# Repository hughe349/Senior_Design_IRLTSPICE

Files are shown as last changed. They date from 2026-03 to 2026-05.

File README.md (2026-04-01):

# IRLTSPICE - A Senior Design Project
 > *Zach DeNeve, Parker Hitchcock, Clayton Hughes, Micah Samuel*

## Overview

LTspice + irl = IRLTSPICE! IRLTSPICE is a configuratble analog circuit.

## Project Structure
The senior design project uses a monorepo architecture with the following sub-directories:
- `hardware/` Hardware schematics
- `firmware/` Microcontroller firmware
- `software/` On-PC software
- `evilware/` Evil Circuits and Code

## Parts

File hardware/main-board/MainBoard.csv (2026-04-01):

Reference | Qty | Value | DNP | DKPN | Exclude from BOM | Exclude from Board | Footprint | Datasheet
U31 | 1 | XTPS55285VALR |  | XTPS55285VALR |  |  | SeniorDesignFP:TPS55285 | https://www.ti.com/lit/gpn/tps55285
Cout3 | 1 | 33u |  | TPSB336K016R0350 |  |  | Capacitor_Tantalum_SMD:CP_EIA-3528-21_Kemet-B_HandSolder | ~
U32 | 1 | TPS54202DDC |  | TPS54202DDCR |  |  | Package_TO_SOT_SMD:SOT-23-6 | http://www.ti.com/lit/ds/symlink/tps54202.pdf
U28 | 1 | TL071 |  | TL071HIDR |  |  | Package_SO:SOIC-8_3.9x4.9mm_P1.27mm | http://www.ti.com/lit/ds/symlink/tl071.pdf
U25 | 1 | TL071 |  | TL071HIDR |  |  | Package_SO:SOIC-8_3.9x4.9mm_P1.27mm | http://www.ti.com/lit/ds/symlink/tl071.pdf
U22 | 1 | TL071 |  | TL071HIDR |  |  | Package_SO:SOIC-8_3.9x4.9mm_P1.27mm | http://www.ti.com/lit/ds/symlink/tl071.pdf
U19 | 1 | TL071 |  | TL071HIDR |  |  | Package_SO:SOIC-8_3.9x4.9mm_P1.27mm | http://www.ti.com/lit/ds/symlink/tl071.pdf
U16 | 1 | TL071 |  | TL071HIDR |  |  | Package_SO:SOIC-8_3.9x4.9mm_P1.27mm | http://www.ti.com/lit/ds/symlink/tl071.pdf
U13 | 1 | TL071 |  | TL071HIDR |  |  | Package_SO:SOIC-8_3.9x4.9mm_P1.27mm | http://www.ti.com/lit/ds/symlink/tl071.pdf
U10 | 1 | TL071 |  | TL071HIDR |  |  | Package_SO:SOIC-8_3.9x4.9mm_P1.27mm | http://www.ti.com/lit/ds/symlink/tl071.pdf
U7 | 1 | TL071 |  | TL071HIDR |  |  | Package_SO:SOIC-8_3.9x4.9mm_P1.27mm | http://www.ti.com/lit/ds/symlink/tl071.pdf
U6 | 1 | TL071 |  | TL071HIDR |  |  | Package_SO:SOIC-8_3.9x4.9mm_P1.27mm | http://www.ti.com/lit/ds/symlink/tl071.pdf
U5 | 1 | TL071 |  | TL071HIDR |  |  | Package_SO:SOIC-8_3.9x4.9mm_P1.27mm | http://www.ti.com/lit/ds/symlink/tl071.pdf
U4 | 1 | TL071 |  | TL071HIDR |  |  | Package_SO:SOIC-8_3.9x4.9mm_P1.27mm | http://www.ti.com/lit/ds/symlink/tl071.pdf
U3 | 1 | TL071 |  | TL071HIDR |  |  | Package_SO:SOIC-8_3.9x4.9mm_P1.27mm | http://www.ti.com/lit/ds/symlink/tl071.pdf
U37 | 1 | STM32F091RCTx |  | STM32F091RC |  |  | Package_QFP:LQFP-64_10x10mm_P0.5mm | https://www.st.com/resource/en/datasheet/stm32f091rc.pdf
L2 | 1 | 10u |  | SRN6045-100M |  |  | Inductor_SMD:L_Bourns_SRN6045TA | ~
SW4 | 1 | SW_SPST |  | SKQGABE010 |  |  | Button_Switch_SMD:SW_SPST_SKQG_WithoutStem | ~
SW3 | 1 | SW_SPST |  | SKQGABE010 |  |  | Button_Switch_SMD:SW_SPST_SKQG_WithoutStem | ~
D12 | 1 | BLUELED |  | QBLP631-IB5-2897 |  |  | Diode_SMD:D_0805_2012Metric_Pad1.15x1.40mm_HandSolder | ~
J9 | 1 | Barrel_Jack |  | PJ-063AH |  |  | Connector_BarrelJack:BarrelJack_CUI_PJ-063AH_Horizontal | ~
SW2 | 1 | SW_SP3T |  | OS103011MS8QP1 |  |  | Button_Switch_THT:SW_Slide_SP3T_Straight_CK_OS103012MU1QP1 | ~
SW1 | 1 | SW_SP3T |  | OS103011MS8QP1 |  |  | Button_Switch_THT:SW_Slide_SP3T_Straight_CK_OS103012MU1QP1 | ~
L1 | 1 | 12u |  | NPI43C120MTRF |  |  | SeniorDesignFP:IND_4532-WE-PD2_WRE-L | ~
Cinx1 | 1 | 4.7u |  | MSASU32MSB7475MPNA01 |  |  | Capacitor_SMD:C_1210_3225Metric_Pad1.33x2.70mm_HandSolder | ~
D13 | 1 | REDLED |  | LS R976-NR-1-0-20-R18 |  |  | Diode_SMD:D_0805_2012Metric_Pad1.15x1.40mm_HandSolder | ~
D9 | 1 | REDLED |  | LS R976-NR-1-0-20-R18 |  |  | Diode_SMD:D_0805_2012Metric_Pad1.15x1.40mm_HandSolder | ~
C22 | 1 | 10µF |  | LMK107BBJ106MALT |  |  | Capacitor_SMD:C_0603_1608Metric_Pad1.08x0.95mm_HandSolder | ~
C21 | 1 | 10µF |  | LMK107BBJ106MALT |  |  | Capacitor_SMD:C_0603_1608Metric_Pad1.08x0.95mm_HandSolder | ~
U2 | 1 | LM7321MAX/NOPB |  | LM7321MAX/NOPB |  |  | Package_SO:SOIC-8_3.9x4.9mm_P1.27mm | https://www.ti.com/lit/ds/symlink/lm7321.pdf?HQS=dis-dk-null-digikeymode-dsf-pf-null-wwe&ts=1774276721362
U33 | 1 | LM2776 |  | LM2776DBVR |  |  | Package_TO_SOT_SMD:SOT-23-6 | http://www.ti.com/lit/ds/symlink/lm2776.pdf
D14 | 1 | GREENLED |  | LG R971-KN-1-0-20-R18 |  |  | Diode_SMD:D_0805_2012Metric_Pad1.15x1.40mm_HandSolder | ~
D10 | 1 | GREENLED |  | LG R971-KN-1-0-20-R18 |  |  | Diode_SMD:D_0805_2012Metric_Pad1.15x1.40mm_HandSolder | ~
Cout1 | 1 | 47u |  | GRM32ER61C476KE15L |  |  | Capacitor_SMD:C_0805_2012Metric_Pad1.18x1.45mm_HandSolder | ~
Ccomp2 | 1 | 15n |  | GRM155R71C153KA01D |  |  | Capacitor_SMD:C_0402_1005Metric_Pad0.74x0.62mm_HandSolder | ~
Cboot3 | 1 | 100nF |  | GRM155R71C104KA88D |  |  | Capacitor_SMD:C_0402_1005Metric_Pad0.74x0.62mm_HandSolder | ~
Cboot2 | 1 | 100nF |  | GRM155R71C104KA88D |  |  | Capacitor_SMD:C_0402_1005Metric_Pad0.74x0.62mm_HandSolder | ~
Ccomp1 | 1 | 240p |  | GRM1555C1H241JA01D |  |  | Capacitor_SMD:C_0402_1005Metric_Pad0.74x0.62mm_HandSolder | ~
Cff1 | 1 | 56p |  | GRM0335C1E560JA01D |  |  | Capacitor_SMD:C_0201_0603Metric_Pad0.64x0.40mm_HandSolder | ~
U35 | 1 | FT232RL |  | FT232RNL-TUBE |  |  | Package_SO:SSOP-28_5.3x10.2mm_P0.65mm | https://www.ftdichip.com/Support/Documents/DataSheets/ICs/DS_FT232R.pdf
R8 | 1 | 10kΩ |  | ESR03EZPF1002 |  |  | Resistor_SMD:R_0603_1608Metric_Pad0.98x0.95mm_HandSolder | ~
R7 | 1 | 10kΩ |  | ESR03EZPF1002 |  |  | Resistor_SMD:R_0603_1608Metric_Pad0.98x0.95mm_HandSolder | ~
R5 | 1 | 10kΩ |  | ESR03EZPF1002 |  |  | Resistor_SMD:R_0603_1608Metric_Pad0.98x0.95mm_HandSolder | ~
R3 | 1 | 10k |  | ESR03EZPF1002 |  |  | Resistor_SMD:R_0603_1608Metric_Pad0.98x0.95mm_HandSolder | ~
R2 | 1 | 10k |  | ESR03EZPF1002 |  |  | Resistor_SMD:R_0603_1608Metric_Pad0.98x0.95mm_HandSolder | ~
R10 | 1 | 150Ω |  | ERA-3AEB151V |  |  | Resistor_SMD:R_0603_1608Metric_Pad0.98x0.95mm_HandSolder | ~
R9 | 1 | 150Ω |  | ERA-3AEB151V |  |  | Resistor_SMD:R_0603_1608Metric_Pad0.98x0.95mm_HandSolder | ~
R6 | 1 | 150Ω |  | ERA-3AEB151V |  |  | Resistor_SMD:R_0603_1608Metric_Pad0.98x0.95mm_HandSolder | ~
R4 | 1 | 150Ω |  | ERA-3AEB151V |  |  | Resistor_SMD:R_0603_1608Metric_Pad0.98x0.95mm_HandSolder | ~
R1 | 1 | 150Ω |  | ERA-3AEB151V |  |  | Resistor_SMD:R_0603_1608Metric_Pad0.98x0.95mm_HandSolder | ~
Rcomp1 | 1 | 8.87k |  | CRCW04028K87FKED |  |  | Resistor_SMD:R_0402_1005Metric_Pad0.72x0.64mm_HandSolder | ~
Rfbb2 | 1 | 6.04k |  | CRCW04026K04FKED |  |  | Resistor_SMD:R_0402_1005Metric_Pad0.72x0.64mm_HandSolder | ~
Rmode1 | 1 | 24.9k |  | CRCW040224K9FKED |  |  | Resistor_SMD:R_0402_1005Metric_Pad0.72x0.64mm_HandSolder | ~
Rfbb1 | 1 | 22.1k |  | CRCW040222K1FKED |  |  | Resistor_SMD:R_0402_1005Metric_Pad0.72x0.64mm_HandSolder | ~
Rent1 | 1 | 261k |  | CRCW0402261KFKED |  |  | Resistor_SMD:R_0402_1005Metric_Pad0.72x0.64mm_HandSolder | ~
Rfbt2 | 1 | 102k |  | CRCW0402102KFKED |  |  | Resistor_SMD:R_0402_1005Metric_Pad0.72x0.64mm_HandSolder | ~
Rfbt1 | 1 | 100k |  | CRCW0402100KFKED |  |  | Resistor_SMD:R_0402_1005Metric_Pad0.72x0.64mm_HandSolder | ~
Renb1 | 1 | 100k |  | CRCW0402100KFKED |  |  | Resistor_SMD:R_0402_1005Metric_Pad0.72x0.64mm_HandSolder | ~
C19 | 1 | 2.2u |  | CL10B225KP8NNNC |  |  | Capacitor_SMD:C_0603_1608Metric_Pad1.08x0.95mm_HandSolder | ~
C18 | 1 | 2.2u |  | CL10B225KP8NNNC |  |  | Capacitor_SMD:C_0603_1608Metric_Pad1.08x0.95mm_HandSolder | ~
U30 | 1 | CD22M3494MQZ |  | CD22M3494MQZ |  |  | SeniorDesignFP:PLCC44_16P66X16P66_INR-M
U29 | 1 | CD22M3494MQZ |  | CD22M3494MQZ |  |  | SeniorDesignFP:PLCC44_16P66X16P66_INR-M
U24 | 1 | CD22M3494MQZ |  | CD22M3494MQZ |  |  | SeniorDesignFP:PLCC44_16P66X16P66_INR-M
U23 | 1 | CD22M3494MQZ |  | CD22M3494MQZ |  |  | SeniorDesignFP:PLCC44_16P66X16P66_INR-M
U18 | 1 | CD22M3494MQZ |  | CD22M3494MQZ |  |  | SeniorDesignFP:PLCC44_16P66X16P66_INR-M
U17 | 1 | CD22M3494MQZ |  | CD22M3494MQZ |  |  | SeniorDesignFP:PLCC44_16P66X16P66_INR-M
U12 | 1 | CD22M3494MQZ |  | CD22M3494MQZ |  |  | SeniorDesignFP:PLCC44_16P66X16P66_INR-M
U11 | 1 | CD22M3494MQZ |  | CD22M3494MQZ |  |  | SeniorDesignFP:PLCC44_16P66X16P66_INR-M
U1 | 1 | CD22M3494MQZ |  | CD22M3494MQZ |  |  | SeniorDesignFP:PLCC44_16P66X16P66_INR-M
Coutx3 | 1 | 10µF |  | C3225X7R1H106M250AC |  |  | Capacitor_SMD:C_1210_3225Metric_Pad1.33x2.70mm_HandSolder | ~
F4 | 1 | 500mA |  | C2Q500 |  |  | Fuse:Fuse_0603_1608Metric_Pad1.05x0.95mm_HandSolder | ~
F3 | 1 | 500mA |  | C2Q500 |  |  | Fuse:Fuse_0603_1608Metric_Pad1.05x0.95mm_HandSolder | ~
F2 | 1 | 500mA |  | C2Q500 |  |  | Fuse:Fuse_0603_1608Metric_Pad1.05x0.95mm_HandSolder | ~
F1 | 1 | 500mA |  | C2Q500 |  |  | Fuse:Fuse_0603_1608Metric_Pad1.05x0.95mm_HandSolder | ~
Cin3 | 1 | 3.3µF |  | C1608X5R1V335K080AC |  |  | Capacitor_SMD:C_1210_3225Metric_Pad1.33x2.70mm_HandSolder | ~
Cvcc1 | 1 | 4.7u |  | C1608X5R1C475K080AC |  |  | Capacitor_SMD:C_0201_0603Metric_Pad0.64x0.40mm_HandSolder | ~
Cinx2 | 1 | 1µF |  | C1005X5R1V105K050BC |  |  | Capacitor_SMD:C_0402_1005Metric_Pad0.74x0.62mm_HandSolder | ~
Cboot1 | 1 | 100nF |  | C0805C104M5RACTU |  |  | Capacitor_SMD:C_0805_2012Metric_Pad1.18x1.45mm_HandSolder | ~
Coutx1 | 1 | 1µF |  | C0603C105Z8VACTU |  |  | Capacitor_SMD:C_0201_0603Metric_Pad0.64x0.40mm_HandSolder | ~
C30 | 1 | 1µF |  | C0603C105K4RACTU |  |  | Capacitor_SMD:C_0603_1608Metric_Pad1.08x0.95mm_HandSolder | ~
C29 | 1 | 1µF |  | C0603C105K4RACTU |  |  | Capacitor_SMD:C_0603_1608Metric_Pad1.08x0.95mm_HandSolder | ~
C17 | 1 | 1µF |  | C0603C105K4RACTU |  |  | Capacitor_SMD:C_0603_1608Metric_Pad1.08x0.95mm_HandSolder | ~
C13 | 1 | 1µF |  | C0603C105K4RACTU |  |  | Capacitor_SMD:C_0603_1608Metric_Pad1.08x0.95mm_HandSolder | ~
C9 | 1 | 1µF |  | C0603C105K4RACTU |  |  | Capacitor_SMD:C_0603_1608Metric_Pad1.08x0.95mm_HandSolder | ~
C5 | 1 | 1µF |  | C0603C105K4RACTU |  |  | Capacitor_SMD:C_0603_1608Metric_Pad1.08x0.95mm_HandSolder | ~
C1 | 1 | 1µF |  | C0603C105K4RACTU |  |  | Capacitor_SMD:C_0603_1608Metric_Pad1.08x0.95mm_HandSolder | ~
C27 | 1 | 100nF |  | C0603C104K5RACTU |  |  | Capacitor_SMD:C_0603_1608Metric_Pad1.08x0.95mm_HandSolder | ~
C26 | 1 | 100nF |  | C0603C104K5RACTU |  |  | Capacitor_SMD:C_0603_1608Metric_Pad1.08x0.95mm_HandSolder | ~
C25 | 1 | 100nF |  | C0603C104K5RACTU |  |  | Capacitor_SMD:C_0603_1608Metric_Pad1.08x0.95mm_HandSolder | ~
C24 | 1 | 100nF |  | C0603C104K5RACTU |  |  | Capacitor_SMD:C_0603_1608Metric_Pad1.08x0.95mm_HandSolder | ~
C23 | 1 | 100nF |  | C0603C104K5RACTU |  |  | Capacitor_SMD:C_0603_1608Metric_Pad1.08x0.95mm_HandSolder | ~
C20 | 1 | 100nF |  | C0603C104K5RACTU |  |  | Capacitor_SMD:C_0603_1608Metric_Pad1.08x0.95mm_HandSolder | ~
C14 | 1 | 100nF |  | C0603C104K5RACTU |  |  | Capacitor_SMD:C_0603_1608Metric_Pad1.08x0.95mm_HandSolder | ~
C10 | 1 | 100nF |  | C0603C104K5RACTU |  |  | Capacitor_SMD:C_0603_1608Metric_Pad1.08x0.95mm_HandSolder | ~
C6 | 1 | 100nF |  | C0603C104K5RACTU |  |  | Capacitor_SMD:C_0603_1608Metric_Pad1.08x0.95mm_HandSolder | ~
C2 | 1 | 100nF |  | C0603C104K5RACTU |  |  | Capacitor_SMD:C_0603_1608Metric_Pad1.08x0.95mm_HandSolder | ~
C28 | 1 | 10nF |  | C0603C103K5RACTU |  |  | Capacitor_SMD:C_0603_1608Metric_Pad1.08x0.95mm_HandSolder | ~
C15 | 1 | 10nF |  | C0603C103K5RACTU |  |  | Capacitor_SMD:C_0603_1608Metric_Pad1.08x0.95mm_HandSolder | ~
C11 | 1 | 10nF |  | C0603C103K5RACTU |  |  | Capacitor_SMD:C_0603_1608Metric_Pad1.08x0.95mm_HandSolder | ~
C7 | 1 | 10nF |  | C0603C103K5RACTU |  |  | Capacitor_SMD:C_0603_1608Metric_Pad1.08x0.95mm_HandSolder | ~
C3 | 1 | 10nF |  | C0603C103K5RACTU |  |  | Capacitor_SMD:C_0603_1608Metric_Pad1.08x0.95mm_HandSolder | ~
C16 | 1 | 1nF |  | C0603C102K5RACTU |  |  | Capacitor_SMD:C_0603_1608Metric_Pad1.08x0.95mm_HandSolder | ~
C12 | 1 | 1nF |  | C0603C102K5RACTU |  |  | Capacitor_SMD:C_0603_1608Metric_Pad1.08x0.95mm_HandSolder | ~
C8 | 1 | 1nF |  | C0603C102K5RACTU |  |  | Capacitor_SMD:C_0603_1608Metric_Pad1.08x0.95mm_HandSolder | ~
C4 | 1 | 1nF |  | C0603C102K5RACTU |  |  | Capacitor_SMD:C_0603_1608Metric_Pad1.08x0.95mm_HandSolder | ~
FB1 | 1 | 120R |  | BLM18PG121SN1D |  |  | Inductor_SMD:L_0603_1608Metric_Pad1.05x0.95mm_HandSolder | ~
D11 | 1 | BAT60JFILM |  | BAT60JFILM |  |  | Diode_SMD:D_SOD-323_HandSoldering | ~
U27 | 1 | AD5263BRUZ200 |  | AD5263BRUZ200-R7 |  |  | SeniorDesignFP:SOP65P640X120-24N
U26 | 1 | AD5263BRUZ200 |  | AD5263BRUZ200-R7 |  |  | SeniorDesignFP:SOP65P640X120-24N
U21 | 1 | AD5263BRUZ200 |  | AD5263BRUZ200-R7 |  |  | SeniorDesignFP:SOP65P640X120-24N
U20 | 1 | AD5263BRUZ200 |  | AD5263BRUZ200-R7 |  |  | SeniorDesignFP:SOP65P640X120-24N
U15 | 1 | AD5263BRUZ200 |  | AD5263BRUZ200-R7 |  |  | SeniorDesignFP:SOP65P640X120-24N
U14 | 1 | AD5263BRUZ200 |  | AD5263BRUZ200-R7 |  |  | SeniorDesignFP:SOP65P640X120-24N
U9 | 1 | AD5263BRUZ200 |  | AD5263BRUZ200-R7 |  |  | SeniorDesignFP:SOP65P640X120-24N
U8 | 1 | AD5263BRUZ200 |  | AD5263BRUZ200-R7 |  |  | SeniorDesignFP:SOP65P640X120-24N
U38 | 1 | 74HC164 |  | 74HC164D |  |  | Package_SO:SOIC-14_3.9x8.7mm_P1.27mm | https://assets.nexperia.com/documents/data-sheet/74HC_HCT164.pdf
U36 | 1 | 74HC164 |  | 74HC164D |  |  | Package_SO:SOIC-14_3.9x8.7mm_P1.27mm | https://assets.nexperia.com/documents/data-sheet/74HC_HCT164.pdf
U34 | 1 | 74HC164 |  | 74HC164D |  |  | Package_SO:SOIC-14_3.9x8.7mm_P1.27mm | https://assets.nexperia.com/documents/data-sheet/74HC_HCT164.pdf
Cin1 | 1 | 22u |  | 35SVPF22M |  |  | SeniorDesignFP:CAP_EEFK_C_PAN | ~
D8 | 1 | 1N4148WT |  | 1N4148W |  |  | Diode_SMD:D_SOD-123 | https://www.diodes.com/assets/Datasheets/ds30396.pdf
D7 | 1 | 1N4148WT |  | 1N4148W |  |  | Diode_SMD:D_SOD-123 | https://www.diodes.com/assets/Datasheets/ds30396.pdf
D6 | 1 | 1N4148WT |  | 1N4148W |  |  | Diode_SMD:D_SOD-123 | https://www.diodes.com/assets/Datasheets/ds30396.pdf
D5 | 1 | 1N4148WT |  | 1N4148W |  |  | Diode_SMD:D_SOD-123 | https://www.diodes.com/assets/Datasheets/ds30396.pdf
D4 | 1 | 1N4148WT |  | 1N4148W |  |  | Diode_SMD:D_SOD-123 | https://www.diodes.com/assets/Datasheets/ds30396.pdf
D3 | 1 | 1N4148WT |  | 1N4148W |  |  | Diode_SMD:D_SOD-123 | https://www.diodes.com/assets/Datasheets/ds30396.pdf
D2 | 1 | 1N4148WT |  | 1N4148W |  |  | Diode_SMD:D_SOD-123 | https://www.diodes.com/assets/Datasheets/ds30396.pdf
D1 | 1 | 1N4148WT |  | 1N4148W |  |  | Diode_SMD:D_SOD-123 | https://www.diodes.com/assets/Datasheets/ds30396.pdf
J10 | 1 | USB_C_Receptacle_USB2.0_14P |  | 1003-030-01210-TR |  |  | Connector_USB:USB_C_Receptacle_G-Switch_GT-USB-7010ASV | https://www.usb.org/sites/default/files/documents/usb_type-c.zip
J13 | 1 | Conn_01x02_Pin |  |  |  |  | Connector_PinSocket_2.54mm:PinSocket_1x02_P2.54mm_Vertical | ~
J12 | 1 | Conn_01x02_Pin |  |  |  |  | Connector_PinSocket_2.54mm:PinSocket_1x02_P2.54mm_Vertical | ~
J11 | 1 | Conn_02x05_Odd_Even |  |  |  |  | Connector_PinHeader_2.54mm:PinHeader_2x05_P2.54mm_Vertical | ~
J8 | 1 | Conn_01x02_Pin |  |  |  |  | Connector_PinSocket_2.54mm:PinSocket_1x02_P2.54mm_Vertical | ~
J7 | 1 | Conn_01x02_Pin |  |  |  |  | Connector_PinSocket_2.54mm:PinSocket_1x02_P2.54mm_Vertical | ~
J6 | 1 | Conn_01x02_Pin |  |  |  |  | Connector_PinSocket_2.54mm:PinSocket_1x02_P2.54mm_Vertical | ~
J5 | 1 | Conn_01x02_Pin |  |  |  |  | Connector_PinSocket_2.54mm:PinSocket_1x02_P2.54mm_Vertical | ~
J4 | 1 | Conn_01x03_Pin |  |  |  |  | Connector_PinHeader_2.54mm:PinHeader_1x03_P2.54mm_Vertical | ~
J3 | 1 | Conn_01x03_Pin |  |  |  |  | Connector_PinHeader_2.54mm:PinHeader_1x03_P2.54mm_Vertical | ~
J2 | 1 | Conn_01x03_Pin |  |  |  |  | Connector_PinHeader_2.54mm:PinHeader_1x03_P2.54mm_Vertical | ~
J1 | 1 | Conn_01x03_Pin |  |  |  |  | Connector_PinHeader_2.54mm:PinHeader_1x03_P2.54mm_Vertical | ~

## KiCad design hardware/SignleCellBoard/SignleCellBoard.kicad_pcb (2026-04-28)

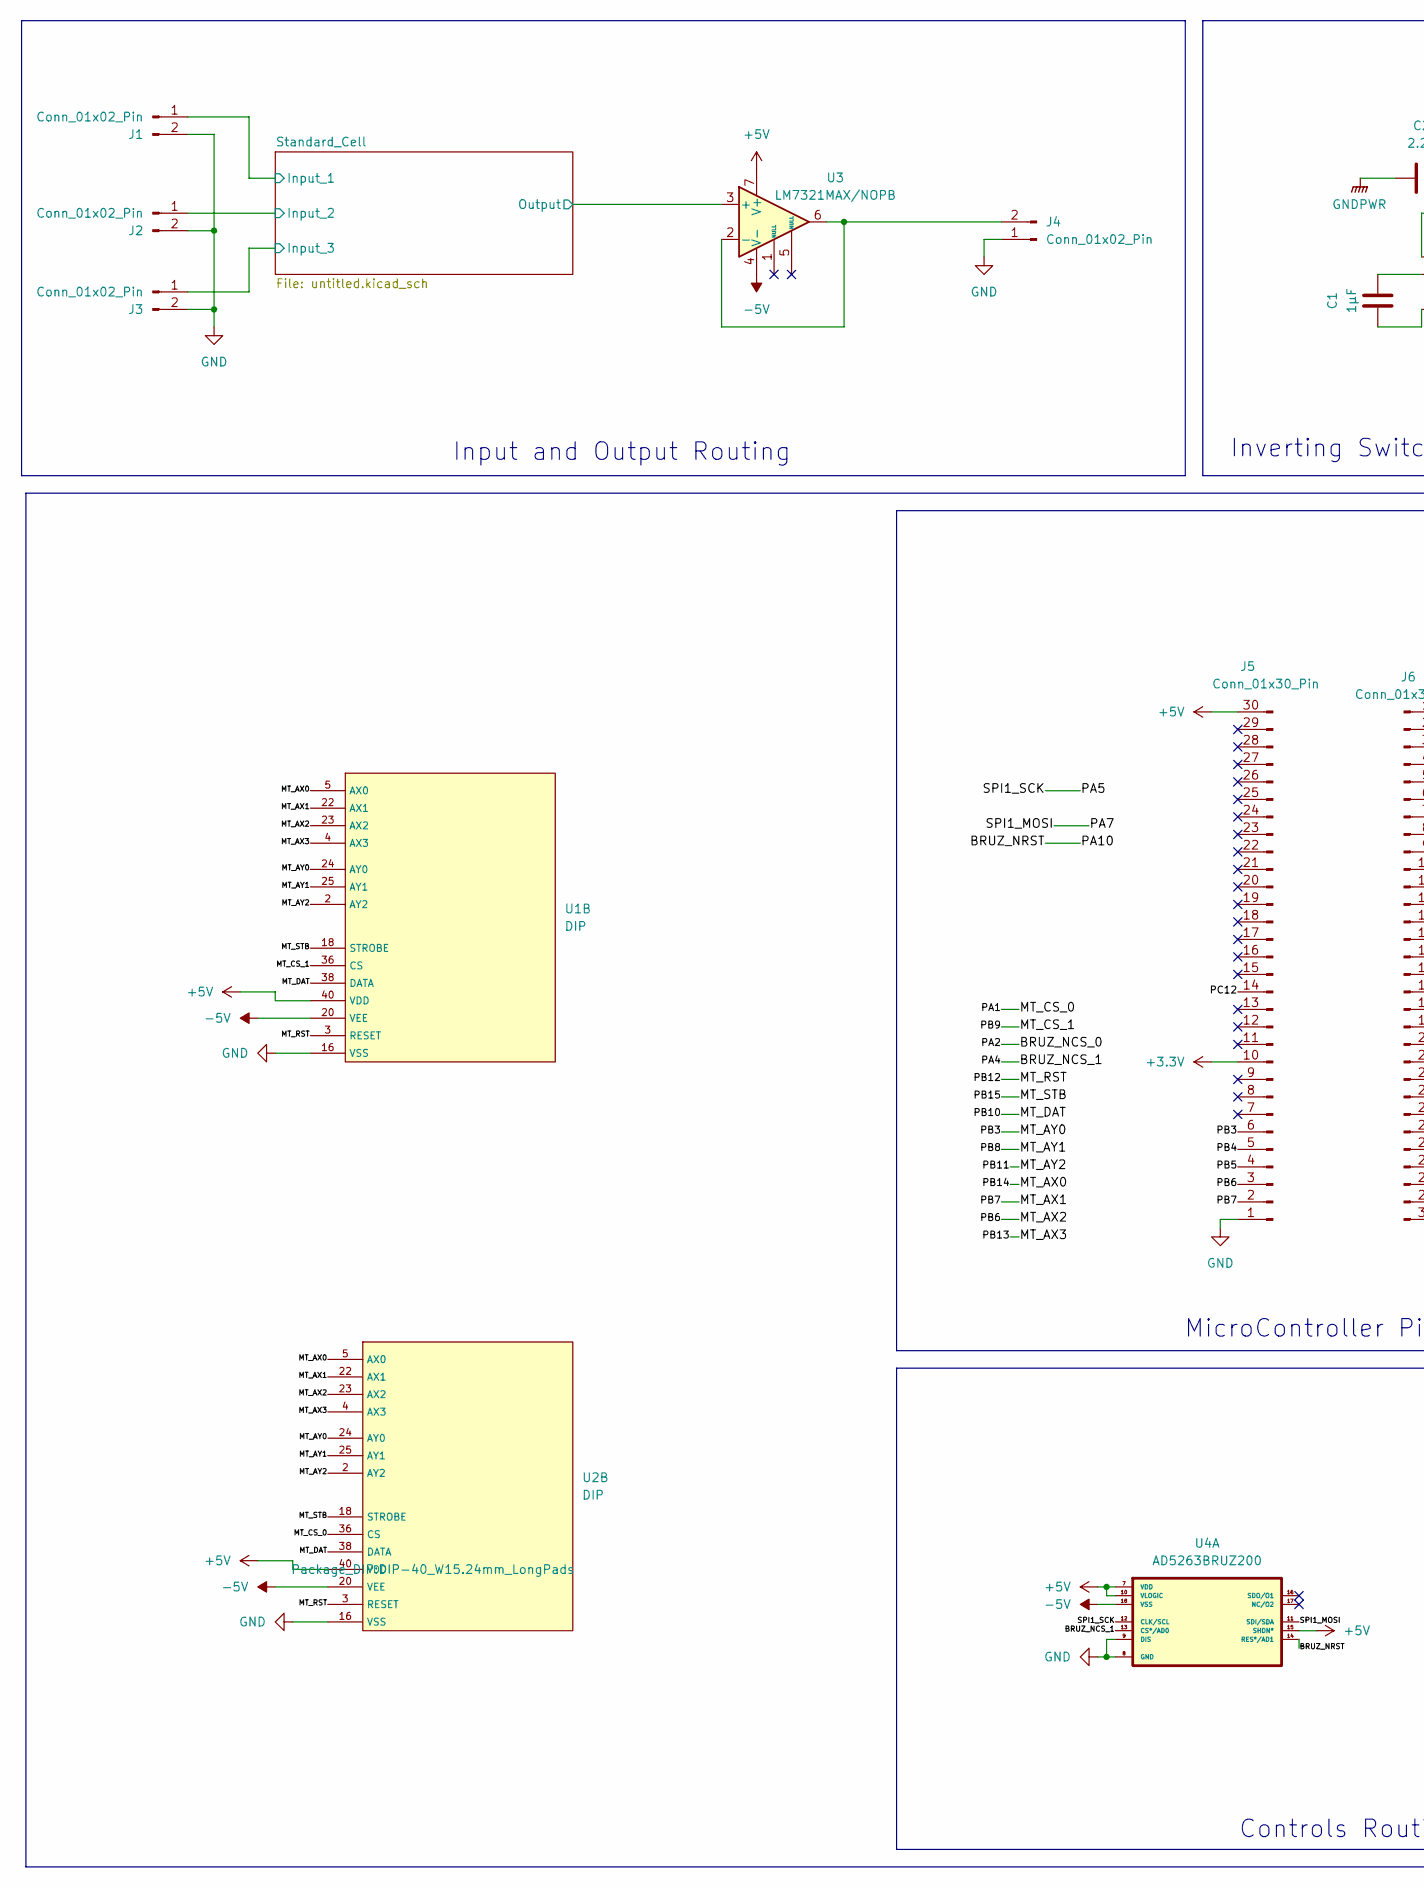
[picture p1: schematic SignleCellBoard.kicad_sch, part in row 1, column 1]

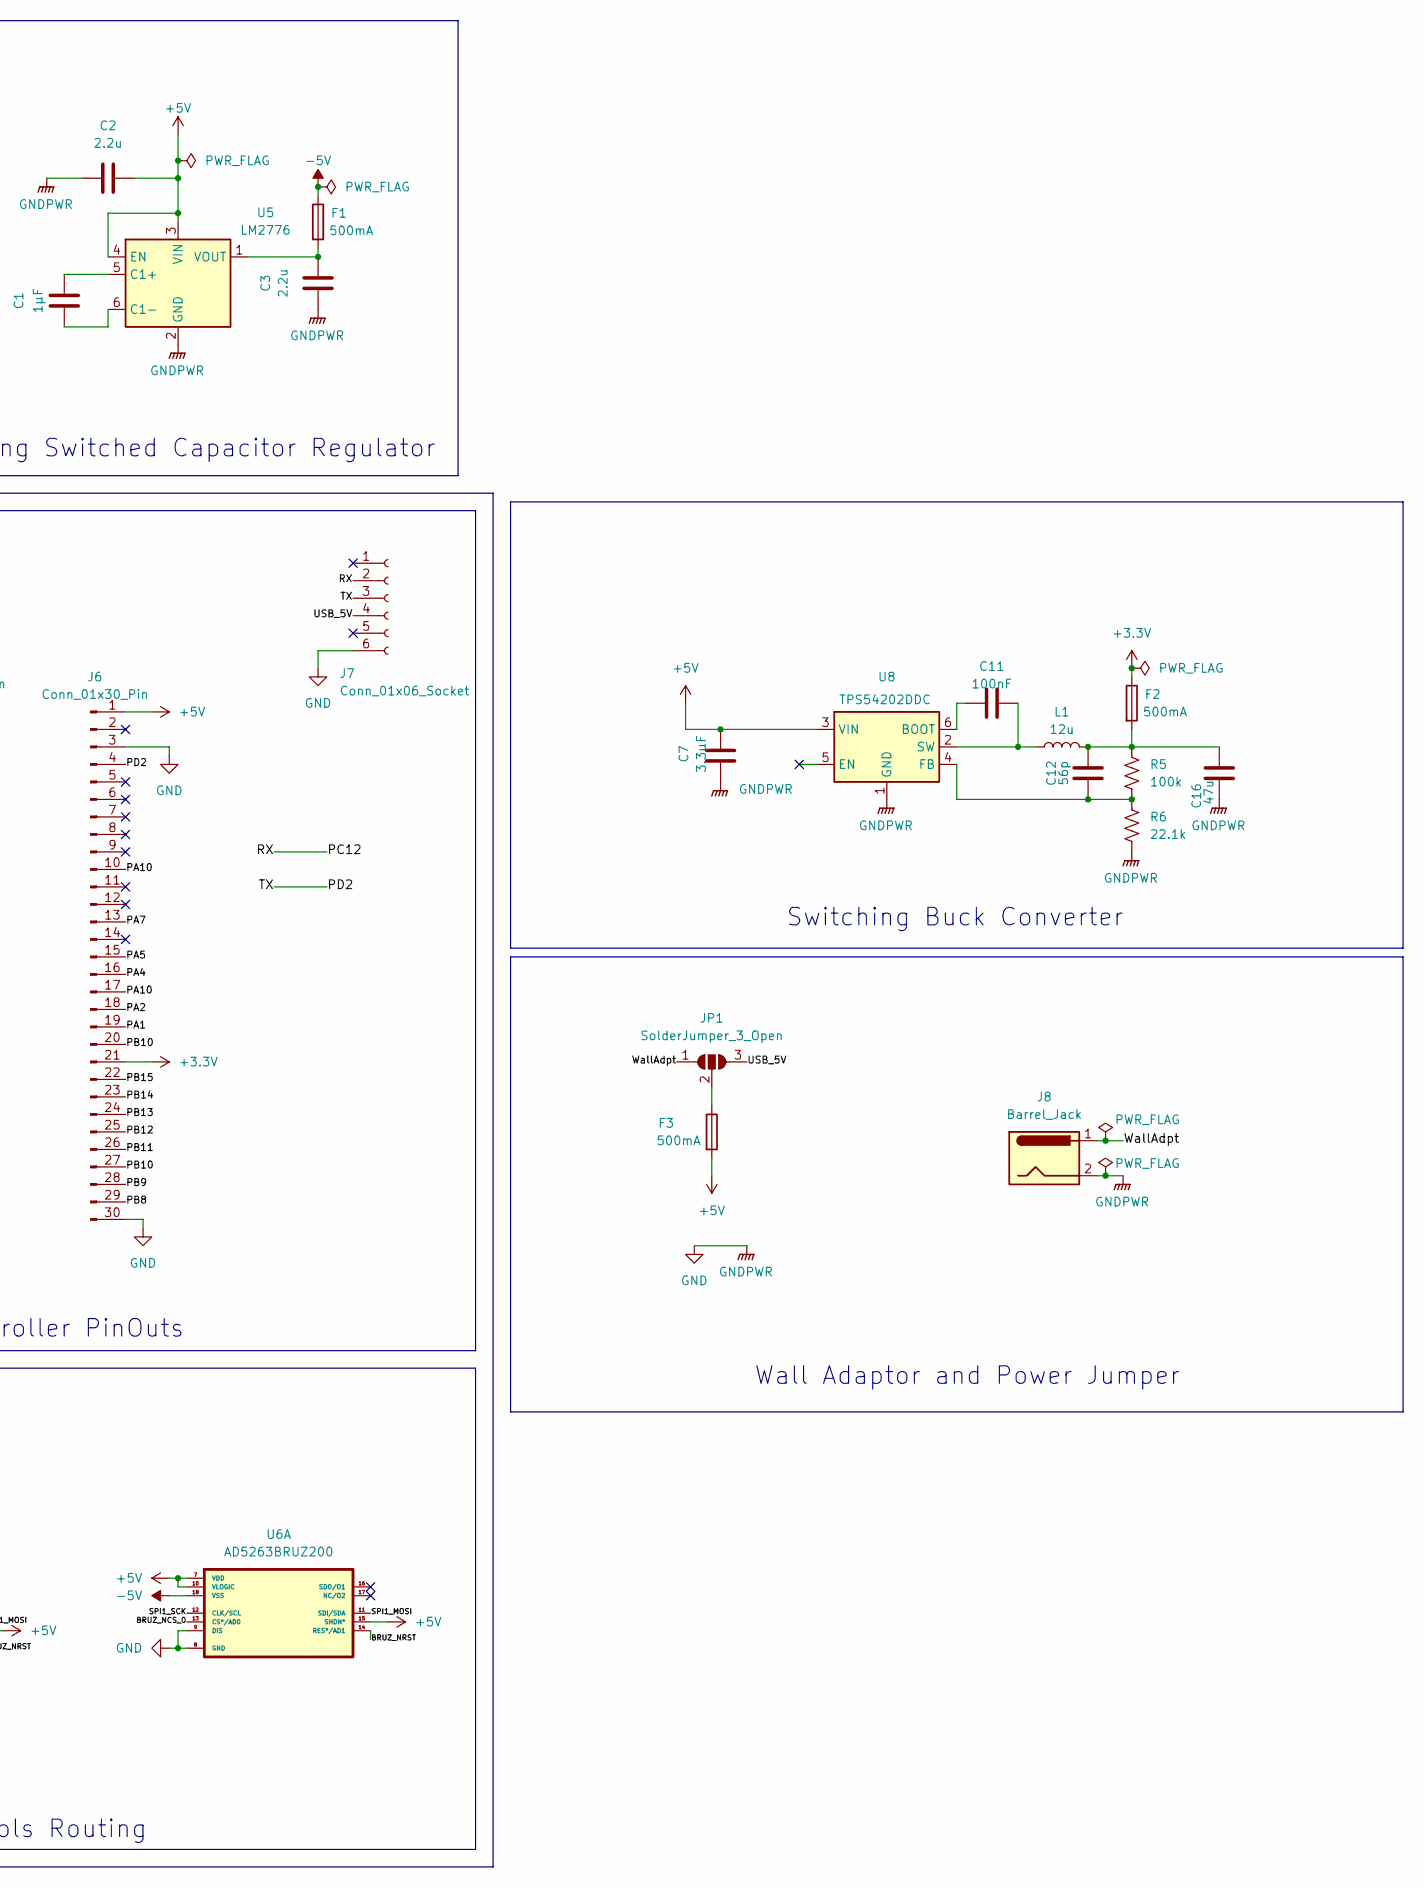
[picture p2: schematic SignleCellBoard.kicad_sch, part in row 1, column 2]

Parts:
C1: 1µF; C_0603_1608Metric_Pad1.08x0.95mm_HandSolder
C2, C3: 2.2u; C_0603_1608Metric_Pad1.08x0.95mm_HandSolder
C7: 3.3µF; C_0805_2012Metric_Pad1.18x1.45mm_HandSolder
C11: 100nF; C_0805_2012Metric_Pad1.18x1.45mm_HandSolder
C12: 56p; C_0603_1608Metric
C16: 47u; C_0805_2012Metric_Pad1.18x1.45mm_HandSolder
F1, F2, F3: 500mA; Fuse_0603_1608Metric_Pad1.05x0.95mm_HandSolder
J1, J2, J3, J4: Conn_01x02_Pin; PinSocket_1x02_P2.54mm_Vertical
J5, J6: Conn_01x30_Pin; PinSocket_1x30_P2.54mm_Vertical
J7: Conn_01x06_Socket; PinSocket_1x06_P2.54mm_Vertical
J8: Barrel_Jack; BarrelJack_CUI_PJ-063AH_Horizontal
JP1: SolderJumper_3_Open; SolderJumper-3_P1.3mm_Open_Pad1.0x1.5mm_NumberLabels
L1: 12u; IND_4532-WE-PD2_WRE-L
R5: 100k; R_0402_1005Metric_Pad0.72x0.64mm_HandSolder
R6: 22.1k; R_0402_1005Metric_Pad0.72x0.64mm_HandSolder
U1, U2: DIP; DIP-40_W15.24mm_LongPads
U3: LM7321MAX/NOPB; SOIC-8_3.9x4.9mm_P1.27mm
U4, U6: AD5263BRUZ200; DIP-24_W15.24mm; MPN AD5263BRUZ200
U5: LM2776; PinHeader_1x06_P2.54mm_Vertical
U8: TPS54202DDC; PinHeader_1x06_P2.54mm_Vertical

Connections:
+3.3V: F2.1, J5.10, J6.21
+5V: C2.2, C7.2, F3.2, J5.30, J6.1, U1.40 (VDD), U2.40 (VDD), U3.7 (V+), U4.7 (VDD), U4.10 (VLOGIC), U4.15 (SHDN*), U5.3 (VIN), U5.4 (EN), U6.7 (VDD), U6.10 (VLOGIC), U6.15 (SHDN*), U8.3 (VIN); also elsewhere on the board
-5V: F1.1, U1.20 (VEE), U2.20 (VEE), U3.4 (V-), U4.18 (VSS), U6.18 (VSS); also elsewhere on the board
/BRUZ_NCS_0: J6.18, U6.13 (CS*/AD0)
/BRUZ_NCS_1: J6.16, U4.13 (CS*/AD0)
/BRUZ_NRST: J6.10, J6.17, U4.14 (RES*/AD1), U6.14 (RES*/AD1)
/MT_AX0: J6.23, U1.5 (AX0), U2.5 (AX0)
/MT_AX1: J5.2, U1.22 (AX1), U2.22 (AX1)
/MT_AX2: J5.3, U1.23 (AX2), U2.23 (AX2)
/MT_AX3: J6.24, U1.4 (AX3), U2.4 (AX3)
/MT_AY0: J5.6, U1.24 (AY0), U2.24 (AY0)
/MT_AY1: J6.29, U1.25 (AY1), U2.25 (AY1)
/MT_AY2: J6.26, U1.2 (AY2), U2.2 (AY2)
/MT_CS_0: J6.19, U2.36 (CS)
/MT_CS_1: J6.28, U1.36 (CS)
/MT_DAT: J6.20, J6.27, U1.38 (DATA), U2.38 (DATA)
/MT_RST: J6.25, U1.3 (RESET), U2.3 (RESET)
/MT_STB: J6.22, U1.18 (STROBE), U2.18 (STROBE)
/PA5: J6.15, U4.12 (CLK/SCL), U6.12 (CLK/SCL)
/PA7: J6.13, U4.11 (SDI/SDA), U6.11 (SDI/SDA)
/PB4: J5.5
/PB5: J5.4
/PC12: J5.14, J7.2
/PD2: J6.4, J7.3
/Standard_Cell/Y0: J1.1; also elsewhere on the board
/Standard_Cell/Y1: J2.1; also elsewhere on the board
/Standard_Cell/Y2: J3.1; also elsewhere on the board
/Standard_Cell/Y3: U3.3 (+); also elsewhere on the board
/USB_5V: J7.4, JP1.3 (B)
/WallAdpt: J8.1, JP1.1 (A)
GND: C2.1, C3.1, C7.1, C16.1, J1.2, J2.2, J3.2, J4.1, J5.1, J6.3, J6.30, J7.6, J8.2, R6.2, U1.16 (VSS), U2.16 (VSS), U4.8 (GND), U4.9 (DIS), U5.2 (GND), U6.8 (GND), U6.9 (DIS), U8.1 (GND); also elsewhere on the board
unnamed: C12.2, C16.2, F2.2, L1.2, R5.1
unnamed: J4.2, U3.2 (-), U3.6
unnamed: F3.1, JP1.2 (C)
unnamed: C1.2, U5.5 (C1+)
unnamed: C1.1, U5.6 (C1-)
unnamed: C3.2, F1.2, U5.1 (VOUT)
unnamed: C11.1, U8.6 (BOOT)
unnamed: C12.1, R5.2, R6.1, U8.4 (FB)
unnamed: C11.2, L1.1, U8.2 (SW)

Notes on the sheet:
MicroController PinOuts
Input and Output Routing
Wall Adaptor and Power Jumper
Inverting Switched Capacitor Regulator
Switching Buck Converter
Controls Routing

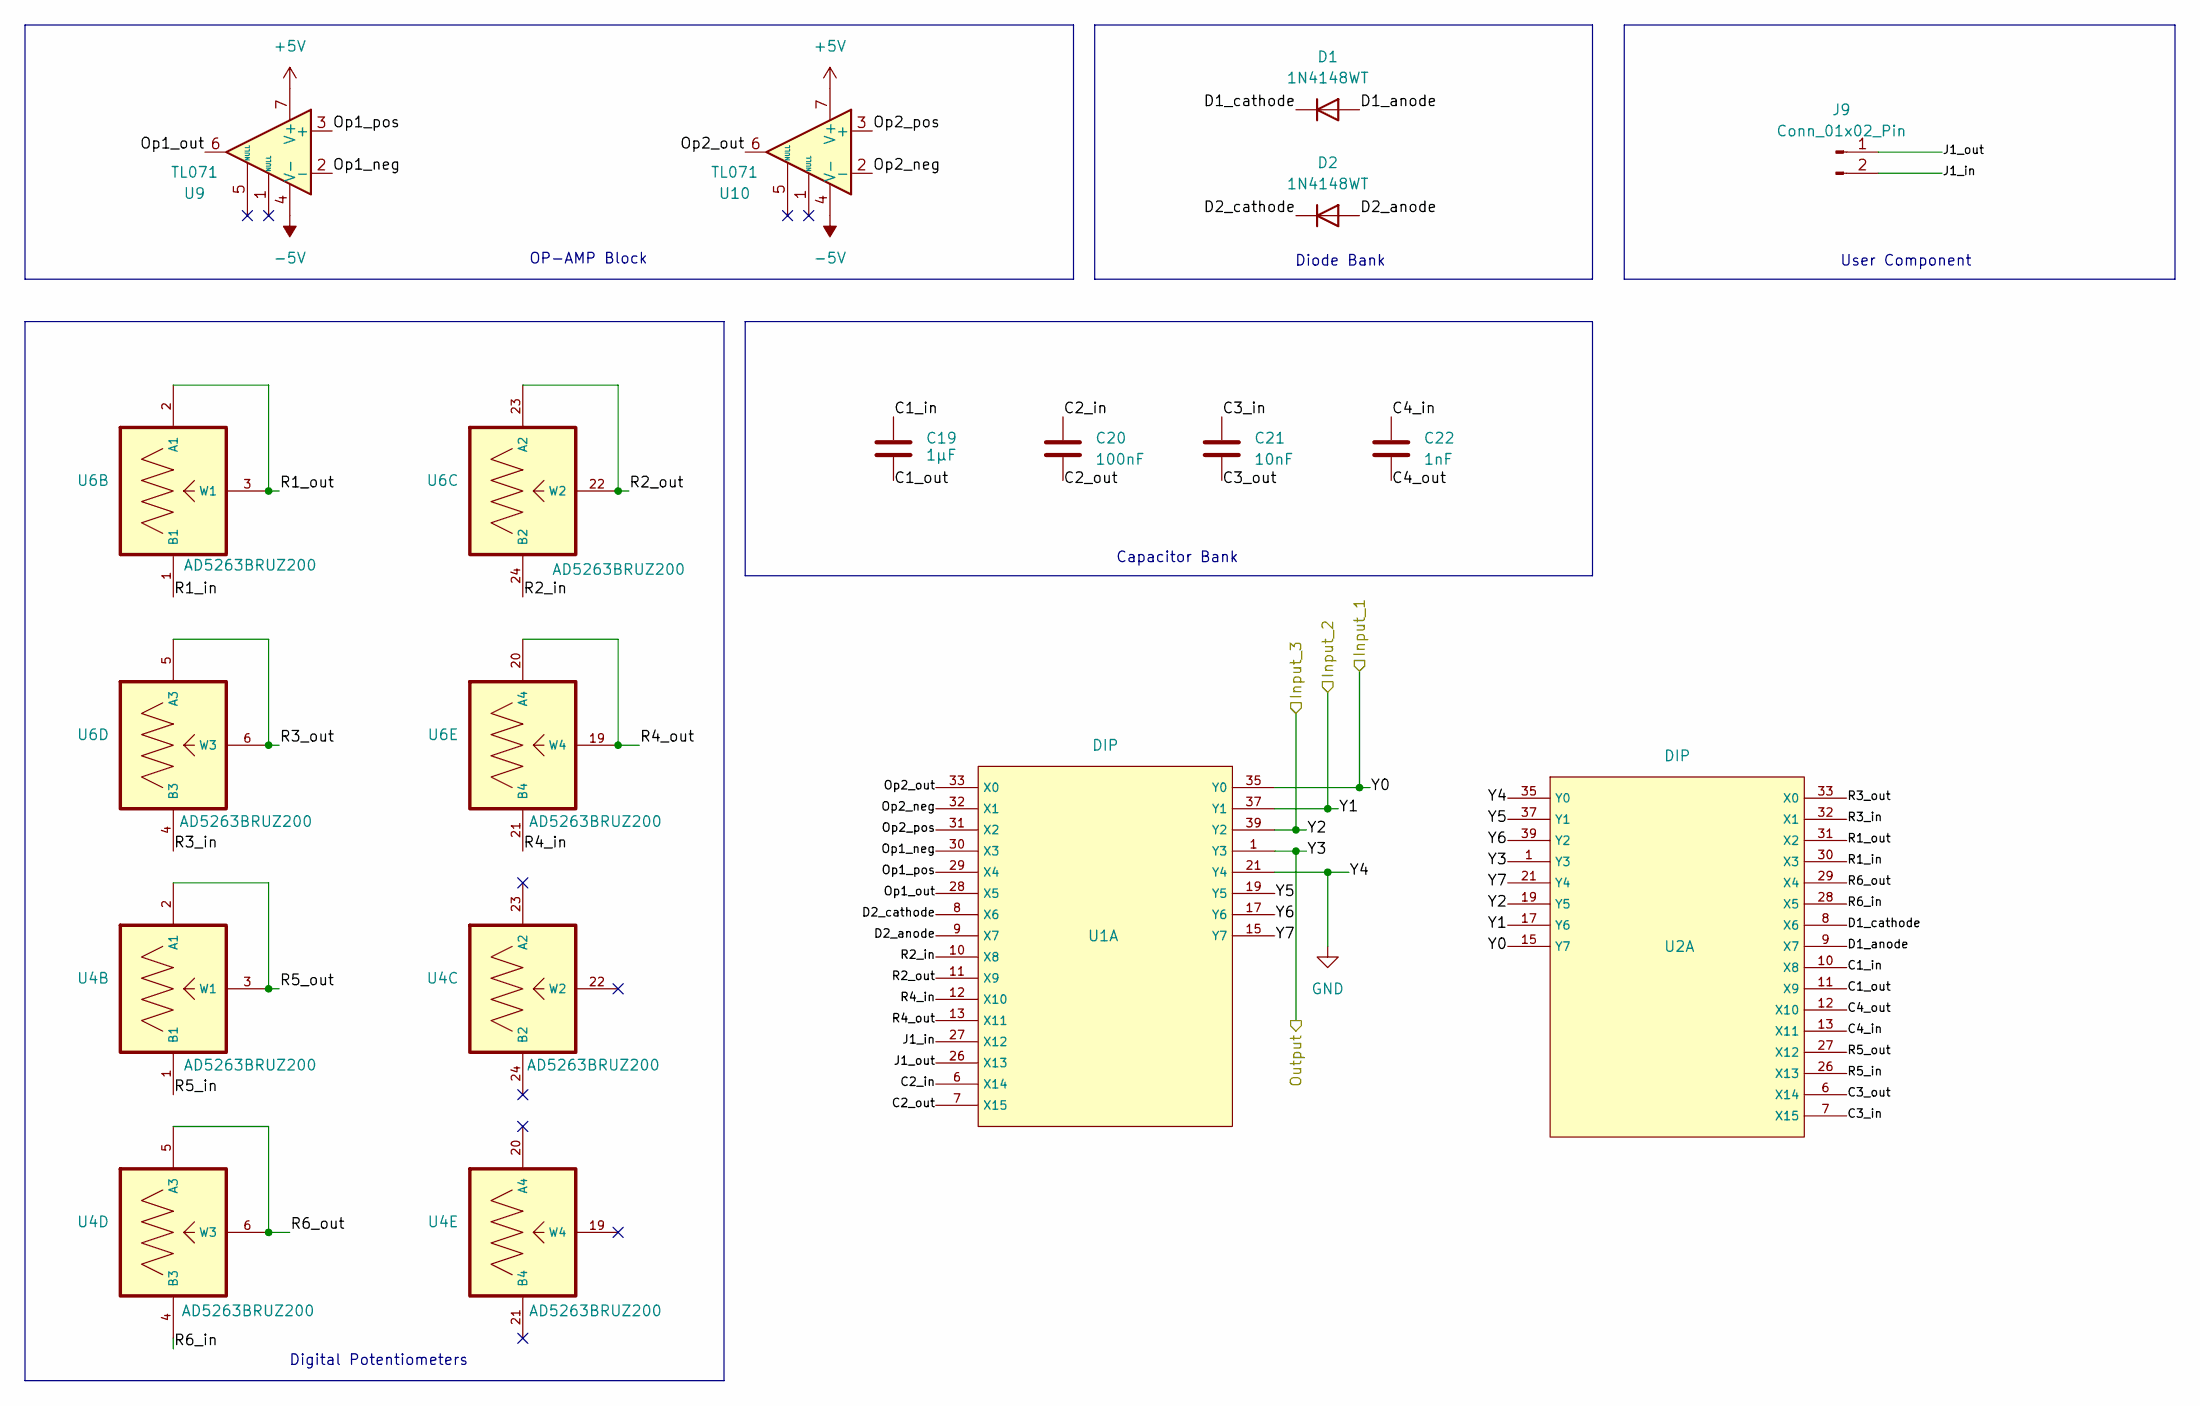
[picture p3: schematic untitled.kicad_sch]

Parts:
C19: 1µF; C_0603_1608Metric_Pad1.08x0.95mm_HandSolder
C20: 100nF; C_0603_1608Metric_Pad1.08x0.95mm_HandSolder
C21: 10nF; C_0603_1608Metric_Pad1.08x0.95mm_HandSolder
C22: 1nF; C_0603_1608Metric_Pad1.08x0.95mm_HandSolder
D1, D2: 1N4148WT; D_SOD-123
J9: Conn_01x02_Pin; PinSocket_1x02_P2.54mm_Vertical
U1, U2: DIP; DIP-40_W15.24mm_LongPads
U4, U6: AD5263BRUZ200; DIP-24_W15.24mm; MPN AD5263BRUZ200
U9, U10: TL071; SOIC-8_3.9x4.9mm_P1.27mm

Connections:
+5V: U9.7 (V+), U10.7 (V+); also elsewhere on the board
-5V: U9.4 (V-), U10.4 (V-); also elsewhere on the board
/Standard_Cell/C1_in: C19.1, U2.10 (X8)
/Standard_Cell/C1_out: C19.2, U2.11 (X9)
/Standard_Cell/C2_in: C20.1, U1.6 (X14)
/Standard_Cell/C2_out: C20.2, U1.7 (X15)
/Standard_Cell/C3_in: C21.1, U2.7 (X15)
/Standard_Cell/C3_out: C21.2, U2.6 (X14)
/Standard_Cell/C4_in: C22.1, U2.13 (X11)
/Standard_Cell/C4_out: C22.2, U2.12 (X10)
/Standard_Cell/D1_anode: D1.2 (A), U2.9 (X7)
/Standard_Cell/D1_cathode: D1.1 (K), U2.8 (X6)
/Standard_Cell/D2_anode: D2.2 (A), U1.9 (X7)
/Standard_Cell/D2_cathode: D2.1 (K), U1.8 (X6)
/Standard_Cell/J1_in: J9.2, U1.27 (X12)
/Standard_Cell/J1_out: J9.1, U1.26 (X13)
/Standard_Cell/Op1_neg: U1.30 (X3), U9.2 (-)
/Standard_Cell/Op1_out: U1.28 (X5), U9.6
/Standard_Cell/Op1_pos: U1.29 (X4), U9.3 (+)
/Standard_Cell/Op2_neg: U1.32 (X1), U10.2 (-)
/Standard_Cell/Op2_out: U1.33 (X0), U10.6
/Standard_Cell/Op2_pos: U1.31 (X2), U10.3 (+)
/Standard_Cell/R1_in: U2.30 (X3), U6.1 (B1)
/Standard_Cell/R1_out: U2.31 (X2), U6.2 (A1), U6.3 (W1)
/Standard_Cell/R2_in: U1.10 (X8), U6.24 (B2)
/Standard_Cell/R2_out: U1.11 (X9), U6.22 (W2), U6.23 (A2)
/Standard_Cell/R3_in: U2.32 (X1), U6.4 (B3)
/Standard_Cell/R3_out: U2.33 (X0), U6.5 (A3), U6.6 (W3)
/Standard_Cell/R4_in: U1.12 (X10), U6.21 (B4)
/Standard_Cell/R4_out: U1.13 (X11), U6.19 (W4), U6.20 (A4)
/Standard_Cell/R5_in: U2.26 (X13), U4.1 (B1)
/Standard_Cell/R5_out: U2.27 (X12), U4.2 (A1), U4.3 (W1)
/Standard_Cell/R6_in: U2.28 (X5), U4.4 (B3)
/Standard_Cell/R6_out: U2.29 (X4), U4.5 (A3), U4.6 (W3)
/Standard_Cell/Y0: U1.35 (Y0), U2.15 (Y7); also elsewhere on the board
/Standard_Cell/Y1: U1.37 (Y1), U2.17 (Y6); also elsewhere on the board
/Standard_Cell/Y2: U1.39 (Y2), U2.19 (Y5); also elsewhere on the board
/Standard_Cell/Y3: U1.1 (Y3), U2.1 (Y3); also elsewhere on the board
/Standard_Cell/Y5: U1.19 (Y5), U2.37 (Y1)
/Standard_Cell/Y6: U1.17 (Y6), U2.39 (Y2)
/Standard_Cell/Y7: U1.15 (Y7), U2.21 (Y4)
GND: U1.21 (Y4), U2.35 (Y0); also elsewhere on the board

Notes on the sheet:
Capacitor Bank
Digital Potentiometers
User Component
Diode Bank
OP-AMP Block

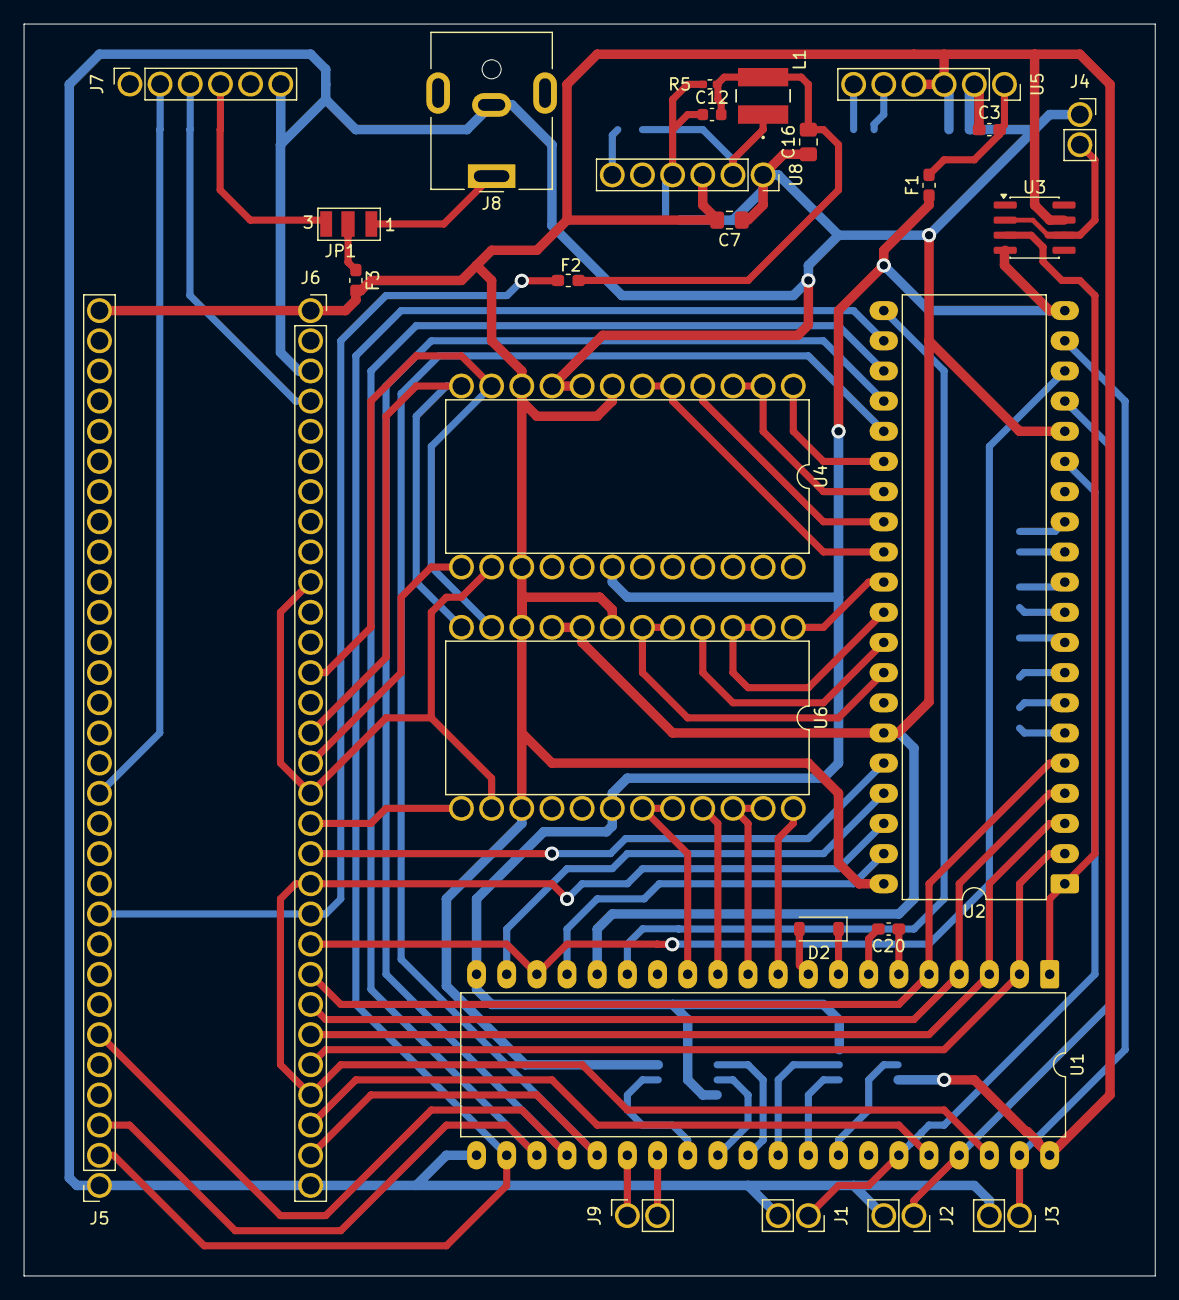
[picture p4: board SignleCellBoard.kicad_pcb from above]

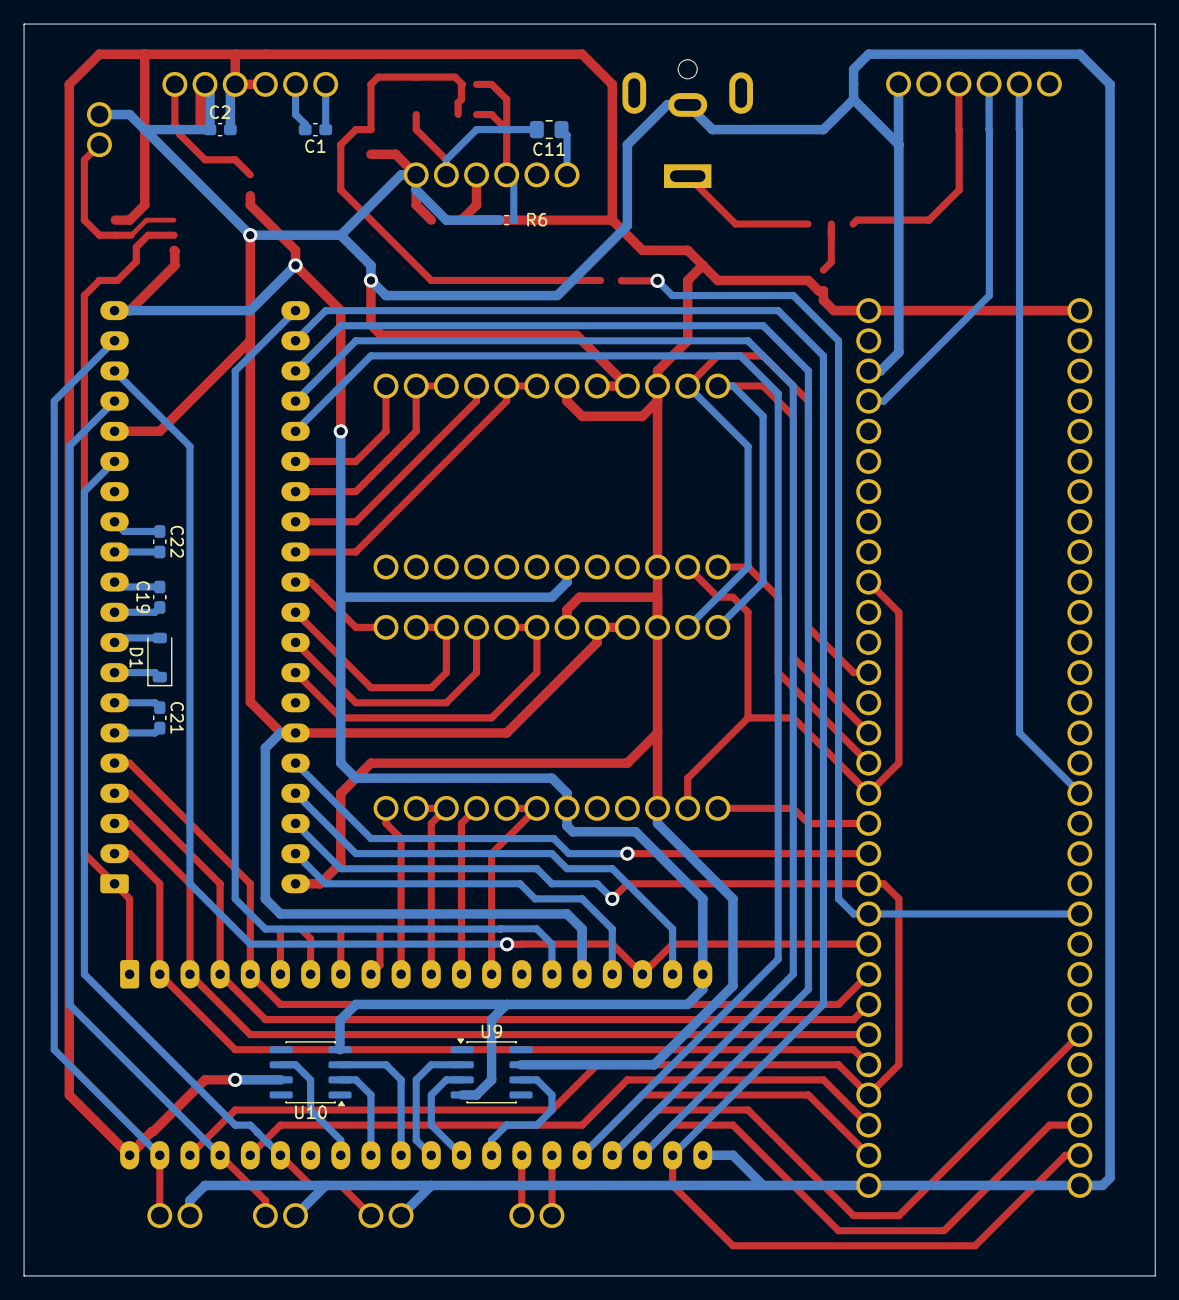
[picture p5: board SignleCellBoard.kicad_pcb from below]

Board: 2 copper layers, 95.2 x 105.4 mm, 38 parts (10 on the bottom side), 73 nets.

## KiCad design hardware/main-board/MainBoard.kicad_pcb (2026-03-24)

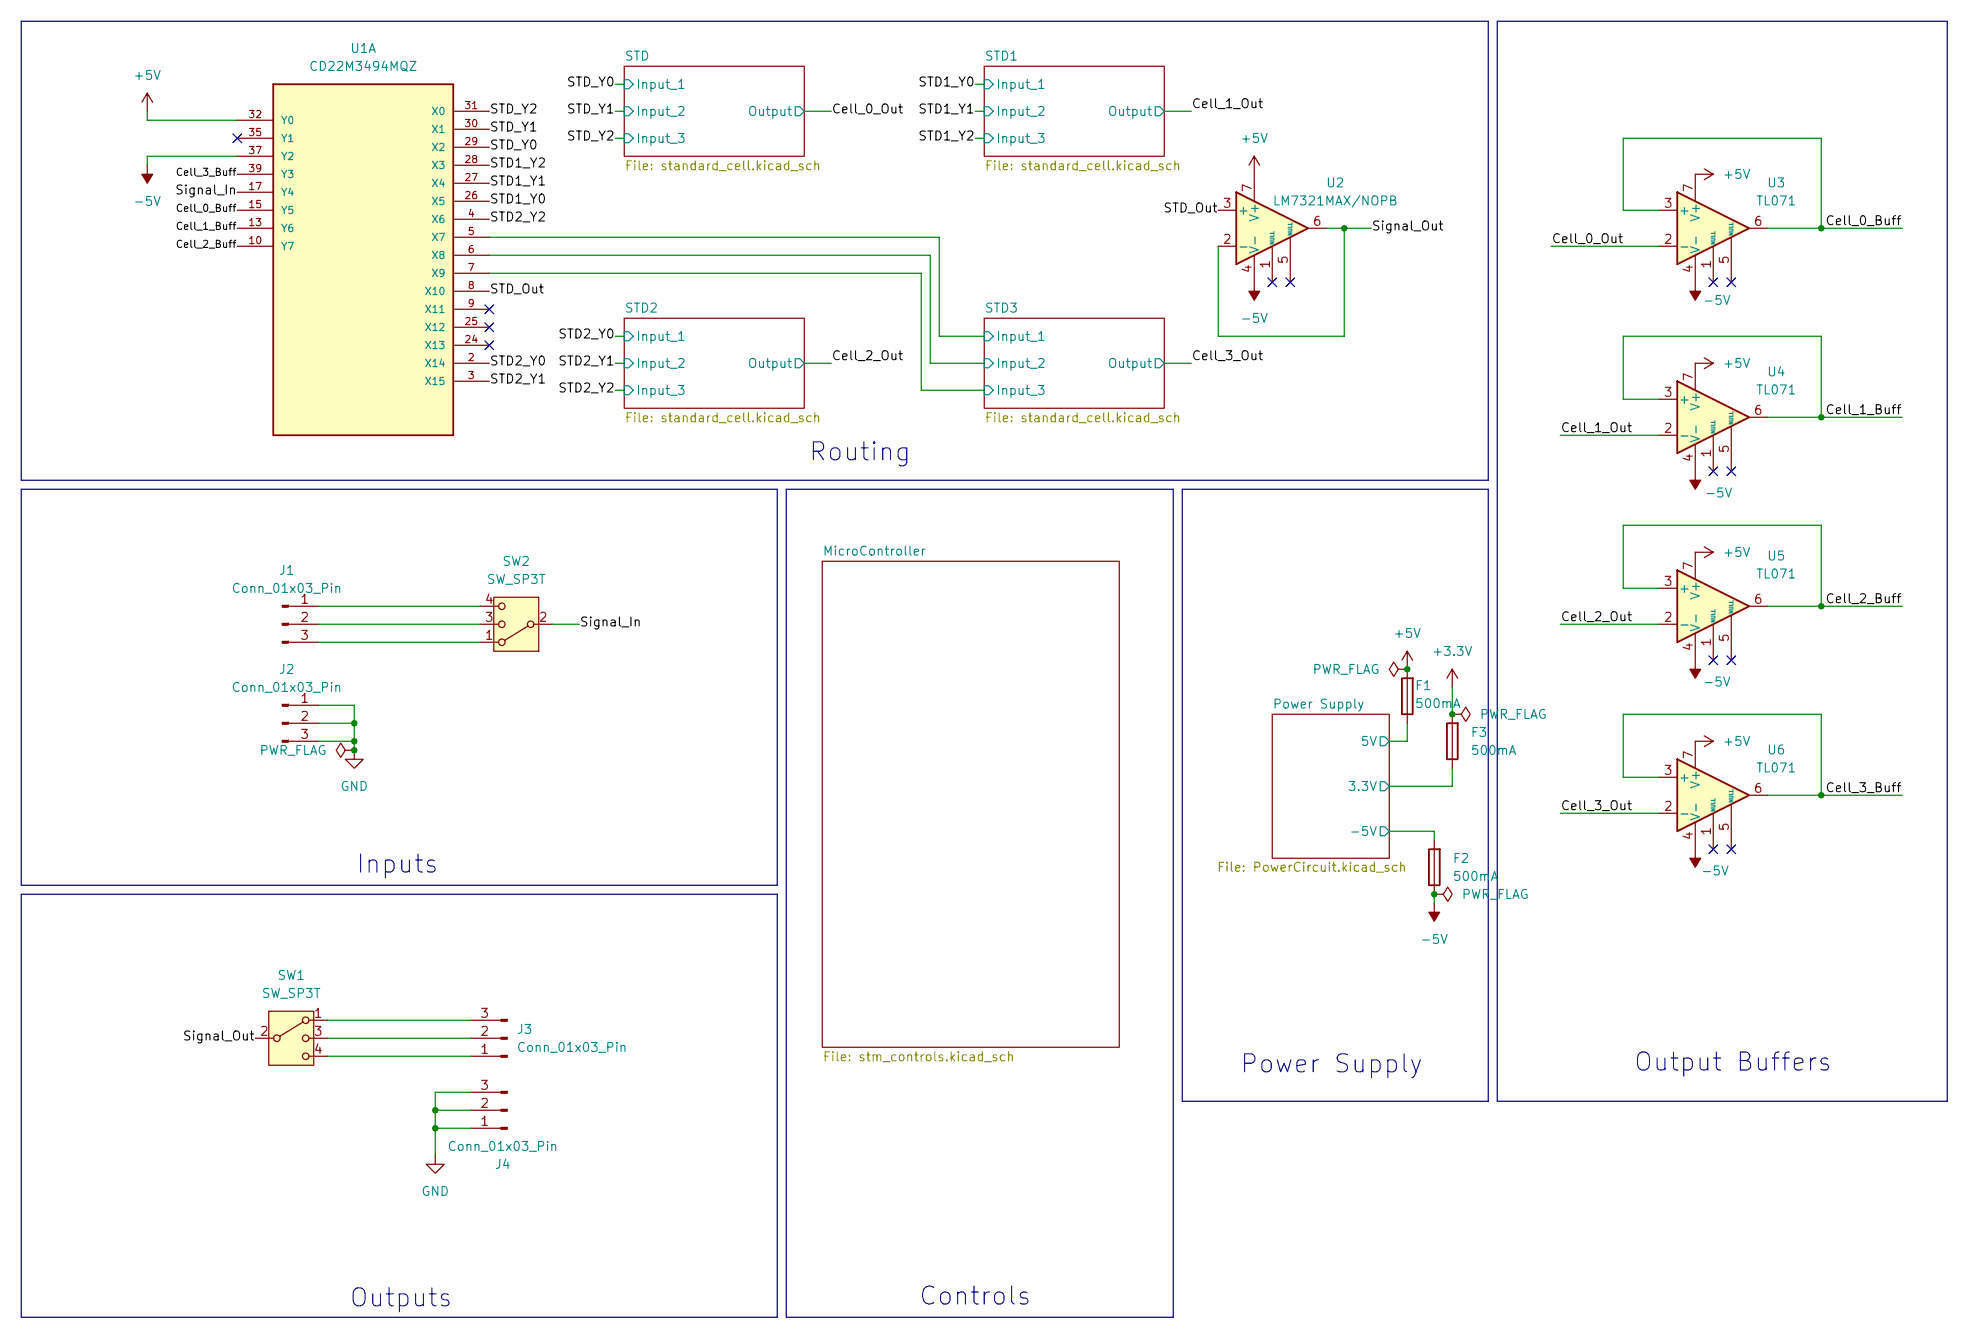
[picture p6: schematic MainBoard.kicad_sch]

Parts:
F1, F2, F3: 500mA; Fuse_0603_1608Metric_Pad1.05x0.95mm_HandSolder
J1, J2, J3, J4: Conn_01x03_Pin; PinHeader_1x03_P2.54mm_Vertical
SW1, SW2: SW_SP3T; SW_Slide_SP3T_Straight_CK_OS103012MU1QP1
U1: CD22M3494MQZ; PLCC44_16P66X16P66_INR-M; PARTREV September 2011
U2: LM7321MAX/NOPB; SOIC-8_3.9x4.9mm_P1.27mm
U3, U4, U5, U6: TL071; SOIC-8_3.9x4.9mm_P1.27mm

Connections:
+3.3V: F3.2; also elsewhere on the board
+5V: F1.2, U1.32 (Y0), U2.7 (V+), U3.7 (V+), U4.7 (V+), U5.7 (V+), U6.7 (V+); also elsewhere on the board
-5V: F2.1, U1.37 (Y2), U2.4 (V-), U3.4 (V-), U4.4 (V-), U5.4 (V-), U6.4 (V-); also elsewhere on the board
/Cell_0_Buff: U1.15 (Y5), U3.3 (+), U3.6
/Cell_0_Out: U3.2 (-); also elsewhere on the board
/Cell_1_Buff: U1.13 (Y6), U4.3 (+), U4.6
/Cell_1_Out: U4.2 (-); also elsewhere on the board
/Cell_2_Buff: U1.10 (Y7), U5.3 (+), U5.6
/Cell_2_Out: U5.2 (-); also elsewhere on the board
/Cell_3_Buff: U1.39 (Y3), U6.3 (+), U6.6
/Cell_3_Out: U6.2 (-); also elsewhere on the board
/Power Supply/3.3V: F3.1; also elsewhere on the board
/Power Supply/5V: F1.1; also elsewhere on the board
/Power Supply/-5V: F2.2; also elsewhere on the board
/STD1_Y0: U1.26 (X5); also elsewhere on the board
/STD1_Y1: U1.27 (X4); also elsewhere on the board
/STD1_Y2: U1.28 (X3); also elsewhere on the board
/STD2_Y0: U1.2 (X14); also elsewhere on the board
/STD2_Y1: U1.3 (X15); also elsewhere on the board
/STD2_Y2: U1.4 (X6); also elsewhere on the board
/STD3/Y0: U1.5 (X7); also elsewhere on the board
/STD3/Y1: U1.6 (X8); also elsewhere on the board
/STD3/Y2: U1.7 (X9); also elsewhere on the board
/STD_Out: U1.8 (X10), U2.3 (+)
/STD_Y0: U1.29 (X2); also elsewhere on the board
/STD_Y1: U1.30 (X1); also elsewhere on the board
/STD_Y2: U1.31 (X0); also elsewhere on the board
/Signal_In: SW2.2, U1.17 (Y4)
/Signal_Out: SW1.2, U2.2 (-), U2.6
GND: J2.1, J2.2, J2.3, J4.1, J4.2, J4.3; also elsewhere on the board
unnamed: J1.1, SW2.4
unnamed: J1.2, SW2.3
unnamed: J1.3, SW2.1
unnamed: J3.1, SW1.4
unnamed: J3.2, SW1.3
unnamed: J3.3, SW1.1

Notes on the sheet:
Inputs
Controls
Outputs
Power Supply
Routing
Output Buffers

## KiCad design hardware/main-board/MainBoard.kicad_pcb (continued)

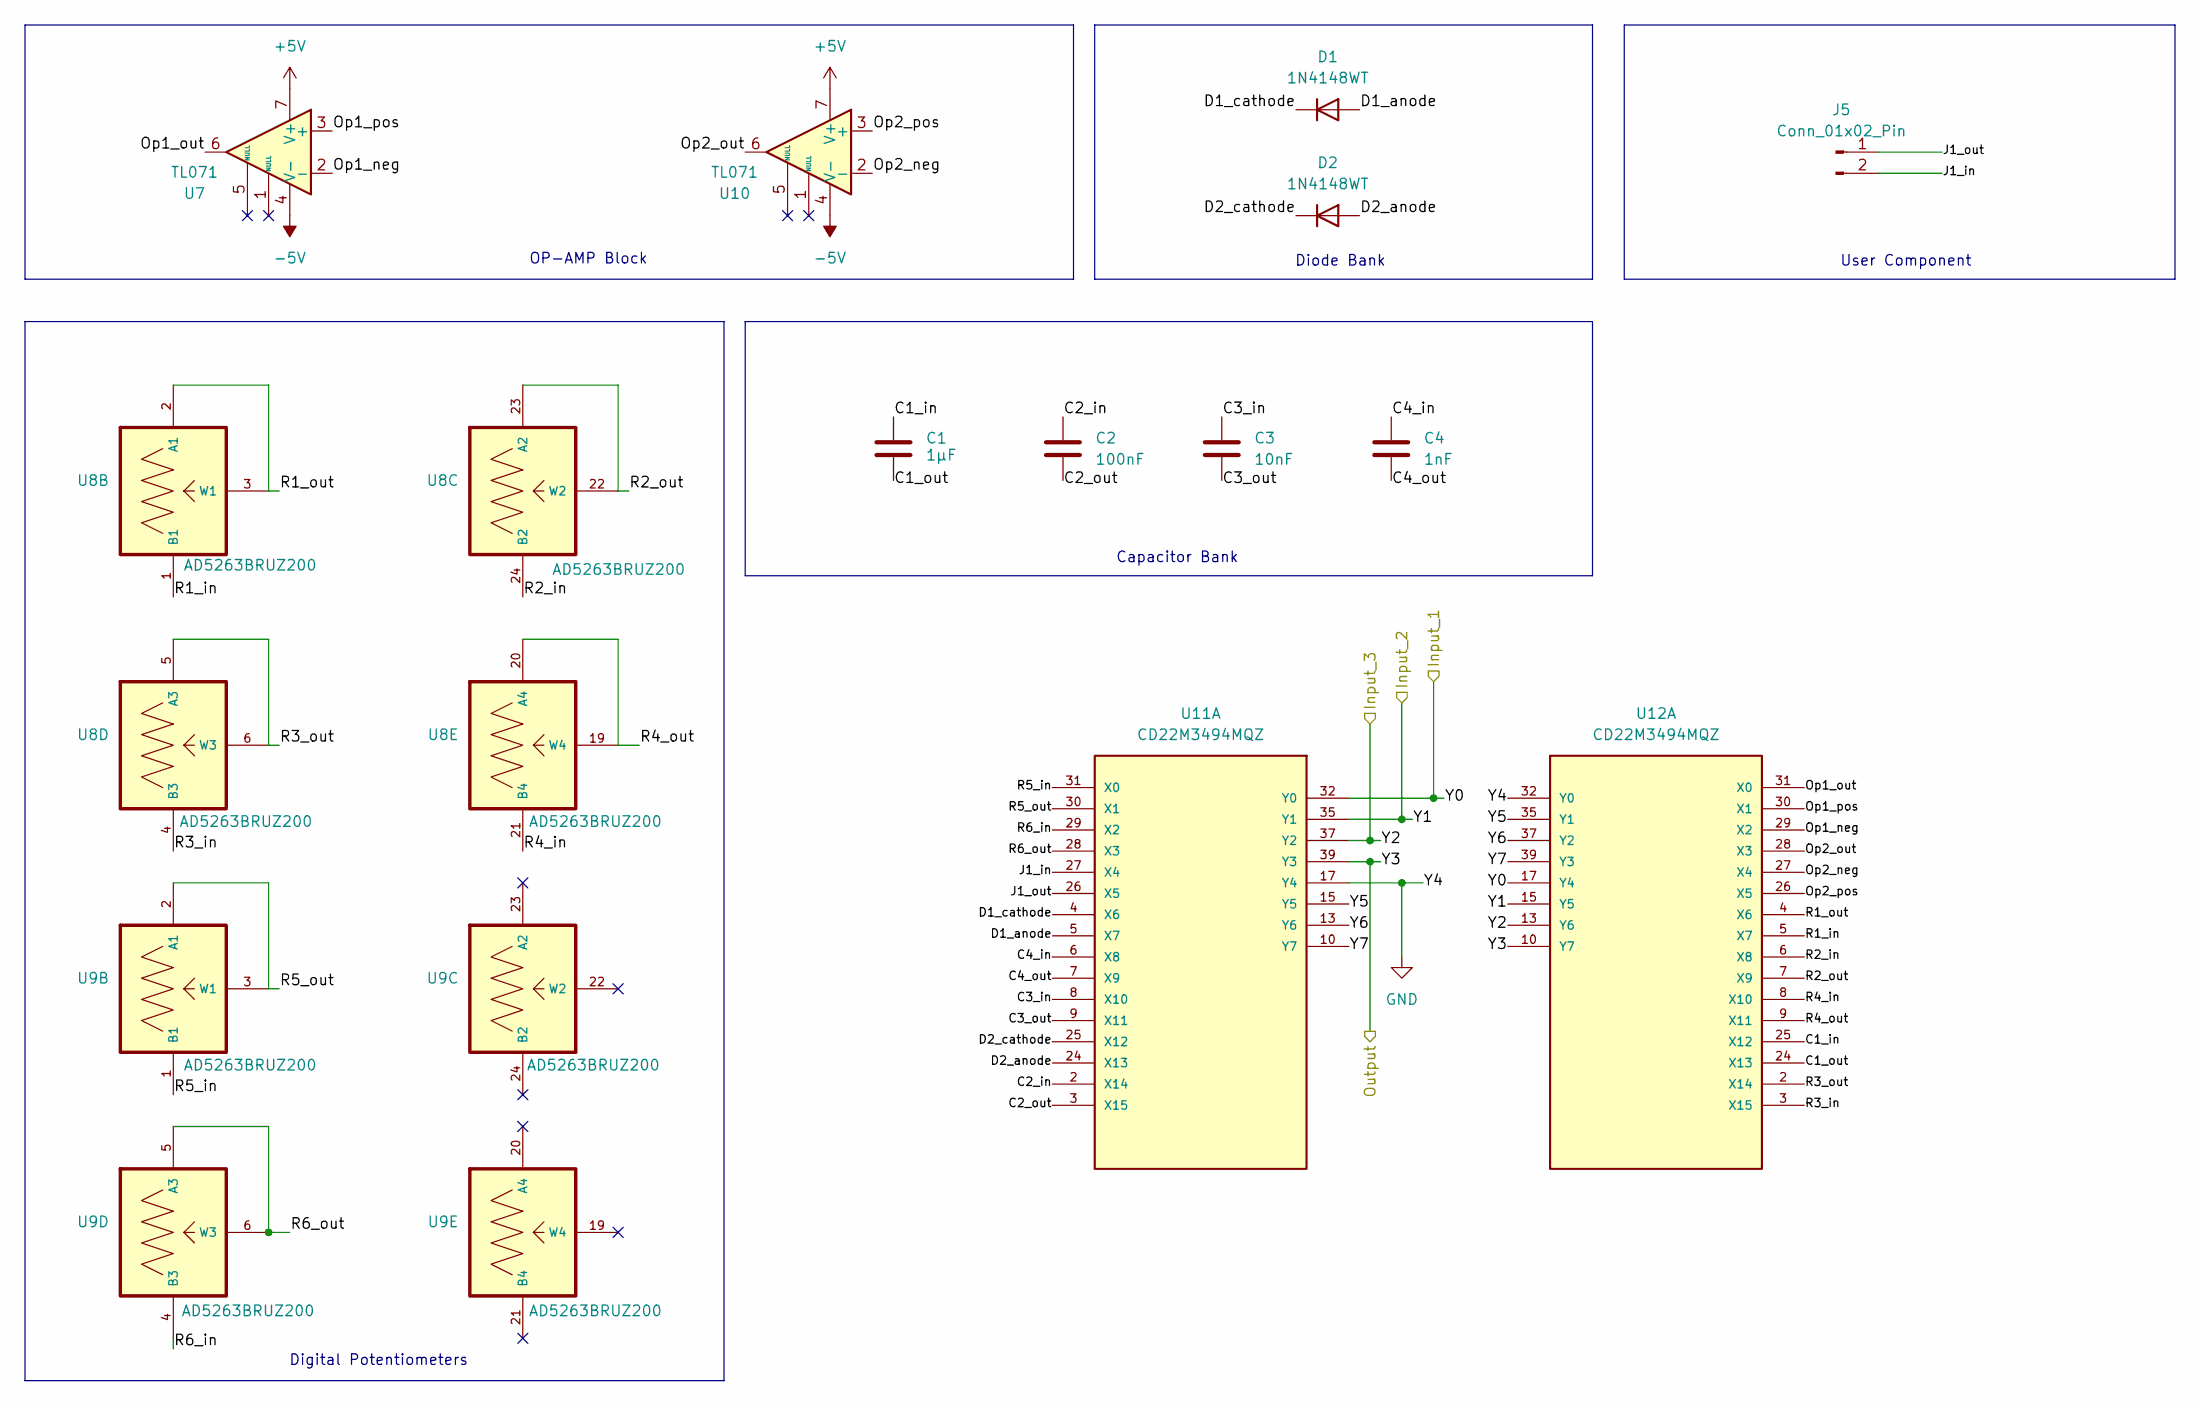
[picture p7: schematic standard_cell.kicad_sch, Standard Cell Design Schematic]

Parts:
C1: 1µF; C_0603_1608Metric_Pad1.08x0.95mm_HandSolder
C2: 100nF; C_0603_1608Metric_Pad1.08x0.95mm_HandSolder
C3: 10nF; C_0603_1608Metric_Pad1.08x0.95mm_HandSolder
C4: 1nF; C_0603_1608Metric_Pad1.08x0.95mm_HandSolder
D1, D2: 1N4148WT; D_SOD-123
J5: Conn_01x02_Pin; PinSocket_1x02_P2.54mm_Vertical
U7, U10: TL071; SOIC-8_3.9x4.9mm_P1.27mm
U8, U9: AD5263BRUZ200; SOP65P640X120-24N
U11, U12: CD22M3494MQZ; PLCC44_16P66X16P66_INR-M; PARTREV September 2011

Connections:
+5V: U7.7 (V+), U10.7 (V+); also elsewhere on the board
-5V: U7.4 (V-), U10.4 (V-); also elsewhere on the board
/Cell_0_Out: U11.39 (Y3), U12.10 (Y7); also elsewhere on the board
/STD/C1_in: C1.1, U12.25 (X12)
/STD/C1_out: C1.2, U12.24 (X13)
/STD/C2_in: C2.1, U11.2 (X14)
/STD/C2_out: C2.2, U11.3 (X15)
/STD/C3_in: C3.1, U11.8 (X10)
/STD/C3_out: C3.2, U11.9 (X11)
/STD/C4_in: C4.1, U11.6 (X8)
/STD/C4_out: C4.2, U11.7 (X9)
/STD/D1_anode: D1.2 (A), U11.5 (X7)
/STD/D1_cathode: D1.1 (K), U11.4 (X6)
/STD/D2_anode: D2.2 (A), U11.24 (X13)
/STD/D2_cathode: D2.1 (K), U11.25 (X12)
/STD/J1_in: J5.2, U11.27 (X4)
/STD/J1_out: J5.1, U11.26 (X5)
/STD/Op1_neg: U7.2 (-), U12.29 (X2)
/STD/Op1_out: U7.6, U12.31 (X0)
/STD/Op1_pos: U7.3 (+), U12.30 (X1)
/STD/Op2_neg: U10.2 (-), U12.27 (X4)
/STD/Op2_out: U10.6, U12.28 (X3)
/STD/Op2_pos: U10.3 (+), U12.26 (X5)
/STD/R1_in: U8.1 (B1), U12.5 (X7)
/STD/R1_out: U8.2 (A1), U8.3 (W1), U12.4 (X6)
/STD/R2_in: U8.24 (B2), U12.6 (X8)
/STD/R2_out: U8.22 (W2), U8.23 (A2), U12.7 (X9)
/STD/R3_in: U8.4 (B3), U12.3 (X15)
/STD/R3_out: U8.5 (A3), U8.6 (W3), U12.2 (X14)
/STD/R4_in: U8.21 (B4), U12.8 (X10)
/STD/R4_out: U8.19 (W4), U8.20 (A4), U12.9 (X11)
/STD/R5_in: U9.1 (B1), U11.31 (X0)
/STD/R5_out: U9.2 (A1), U9.3 (W1), U11.30 (X1)
/STD/R6_in: U9.4 (B3), U11.29 (X2)
/STD/R6_out: U9.5 (A3), U9.6 (W3), U11.28 (X3)
/STD/Y5: U11.15 (Y5), U12.35 (Y1)
/STD/Y6: U11.13 (Y6), U12.37 (Y2)
/STD/Y7: U11.10 (Y7), U12.39 (Y3)
/STD_Y0: U11.32 (Y0), U12.17 (Y4); also elsewhere on the board
/STD_Y1: U11.35 (Y1), U12.15 (Y5); also elsewhere on the board
/STD_Y2: U11.37 (Y2), U12.13 (Y6); also elsewhere on the board
GND: U11.17 (Y4), U12.32 (Y0); also elsewhere on the board

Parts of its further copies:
C5, C9, C13: 1µF; C_0603_1608Metric_Pad1.08x0.95mm_HandSolder
C6, C10, C14: 100nF; C_0603_1608Metric_Pad1.08x0.95mm_HandSolder
C7, C11, C15: 10nF; C_0603_1608Metric_Pad1.08x0.95mm_HandSolder
C8, C12, C16: 1nF; C_0603_1608Metric_Pad1.08x0.95mm_HandSolder
D3, D4, D5, D6, D7, D8: 1N4148WT; D_SOD-123
J6, J7, J8: Conn_01x02_Pin; PinSocket_1x02_P2.54mm_Vertical
U13, U16, U19, U22, U25, U28: TL071; SOIC-8_3.9x4.9mm_P1.27mm

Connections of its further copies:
+5V: U13.7 (V+), U16.7 (V+), U19.7 (V+), U22.7 (V+), U25.7 (V+), U28.7 (V+); also elsewhere on the board
-5V: U13.4 (V-), U16.4 (V-), U19.4 (V-), U22.4 (V-), U25.4 (V-), U28.4 (V-); also elsewhere on the board
/STD1/C1_in: C5.1; also elsewhere on the board
/STD1/C1_out: C5.2; also elsewhere on the board
/STD1/C2_in: C6.1; also elsewhere on the board
/STD1/C2_out: C6.2; also elsewhere on the board
/STD1/C3_in: C7.1; also elsewhere on the board
/STD1/C3_out: C7.2; also elsewhere on the board
/STD1/C4_in: C8.1; also elsewhere on the board
/STD1/C4_out: C8.2; also elsewhere on the board
/STD1/D1_anode: D3.2 (A); also elsewhere on the board
/STD1/D1_cathode: D3.1 (K); also elsewhere on the board
/STD1/D2_anode: D4.2 (A); also elsewhere on the board
/STD1/D2_cathode: D4.1 (K); also elsewhere on the board
/STD1/J1_in: J6.2; also elsewhere on the board
/STD1/J1_out: J6.1; also elsewhere on the board
/STD1/Op1_neg: U13.2 (-); also elsewhere on the board
/STD1/Op1_out: U13.6; also elsewhere on the board
/STD1/Op1_pos: U13.3 (+); also elsewhere on the board
/STD1/Op2_neg: U16.2 (-); also elsewhere on the board
/STD1/Op2_out: U16.6; also elsewhere on the board
/STD1/Op2_pos: U16.3 (+); also elsewhere on the board
/STD2/C1_in: C9.1; also elsewhere on the board
/STD2/C1_out: C9.2; also elsewhere on the board
/STD2/C2_in: C10.1; also elsewhere on the board
/STD2/C2_out: C10.2; also elsewhere on the board
/STD2/C3_in: C11.1; also elsewhere on the board
/STD2/C3_out: C11.2; also elsewhere on the board
/STD2/C4_in: C12.1; also elsewhere on the board
/STD2/C4_out: C12.2; also elsewhere on the board
/STD2/D1_anode: D5.2 (A); also elsewhere on the board
/STD2/D1_cathode: D5.1 (K); also elsewhere on the board
/STD2/D2_anode: D6.2 (A); also elsewhere on the board
/STD2/D2_cathode: D6.1 (K); also elsewhere on the board
/STD2/J1_in: J7.2; also elsewhere on the board
/STD2/J1_out: J7.1; also elsewhere on the board
/STD2/Op1_neg: U19.2 (-); also elsewhere on the board
/STD2/Op1_out: U19.6; also elsewhere on the board
/STD2/Op1_pos: U19.3 (+); also elsewhere on the board
/STD2/Op2_neg: U22.2 (-); also elsewhere on the board
/STD2/Op2_out: U22.6; also elsewhere on the board
/STD2/Op2_pos: U22.3 (+); also elsewhere on the board
/STD3/C1_in: C13.1; also elsewhere on the board
/STD3/C1_out: C13.2; also elsewhere on the board
/STD3/C2_in: C14.1; also elsewhere on the board
/STD3/C2_out: C14.2; also elsewhere on the board
/STD3/C3_in: C15.1; also elsewhere on the board
/STD3/C3_out: C15.2; also elsewhere on the board
/STD3/C4_in: C16.1; also elsewhere on the board
/STD3/C4_out: C16.2; also elsewhere on the board
/STD3/D1_anode: D7.2 (A); also elsewhere on the board
/STD3/D1_cathode: D7.1 (K); also elsewhere on the board
/STD3/D2_anode: D8.2 (A); also elsewhere on the board
/STD3/D2_cathode: D8.1 (K); also elsewhere on the board
/STD3/J1_in: J8.2; also elsewhere on the board
/STD3/J1_out: J8.1; also elsewhere on the board
/STD3/Op1_neg: U25.2 (-); also elsewhere on the board
/STD3/Op1_out: U25.6; also elsewhere on the board
/STD3/Op1_pos: U25.3 (+); also elsewhere on the board
/STD3/Op2_neg: U28.2 (-); also elsewhere on the board
/STD3/Op2_out: U28.6; also elsewhere on the board
/STD3/Op2_pos: U28.3 (+); also elsewhere on the board

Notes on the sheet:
Diode Bank
Digital Potentiometers
User Component
OP-AMP Block
Capacitor Bank

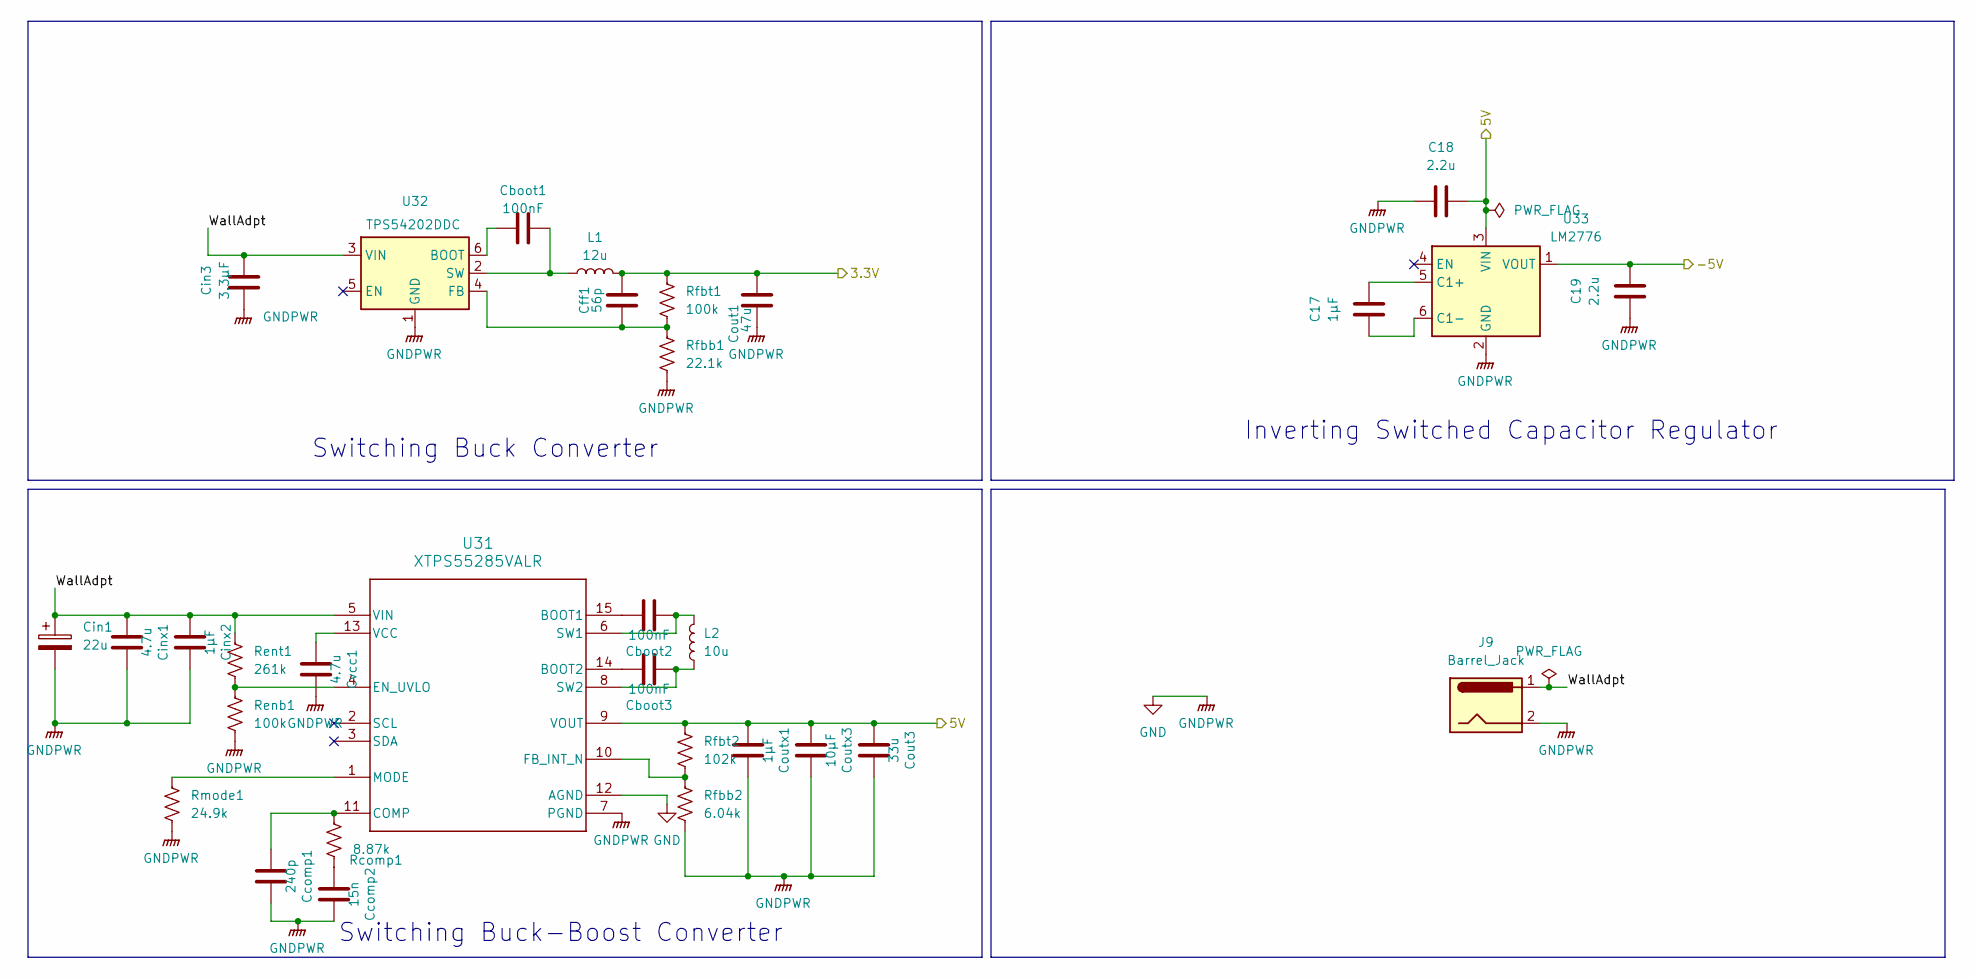
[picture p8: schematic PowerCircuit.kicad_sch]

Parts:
C17: 1µF; C_0603_1608Metric_Pad1.08x0.95mm_HandSolder
C18, C19: 2.2u; C_0603_1608Metric_Pad1.08x0.95mm_HandSolder
Cboot1: 100nF; C_0805_2012Metric_Pad1.18x1.45mm_HandSolder
Cboot2, Cboot3: 100nF; C_0402_1005Metric_Pad0.74x0.62mm_HandSolder
Ccomp1: 240p; C_0402_1005Metric_Pad0.74x0.62mm_HandSolder
Ccomp2: 15n; C_0402_1005Metric_Pad0.74x0.62mm_HandSolder
Cff1: 56p; C_0201_0603Metric_Pad0.64x0.40mm_HandSolder
Cin1: 22u; CAP_EEFK_C_PAN
Cin3: 3.3µF; C_1210_3225Metric_Pad1.33x2.70mm_HandSolder
Cinx1: 4.7u; C_1210_3225Metric_Pad1.33x2.70mm_HandSolder
Cinx2: 1µF; C_0402_1005Metric_Pad0.74x0.62mm_HandSolder
Cout1: 47u; C_0805_2012Metric_Pad1.18x1.45mm_HandSolder
Cout3: 33u; CP_EIA-3528-21_Kemet-B_HandSolder
Coutx1: 1µF; C_0201_0603Metric_Pad0.64x0.40mm_HandSolder
Coutx3: 10µF; C_1210_3225Metric_Pad1.33x2.70mm_HandSolder
Cvcc1: 4.7u; C_0201_0603Metric_Pad0.64x0.40mm_HandSolder
J9: Barrel_Jack; BarrelJack_CUI_PJ-063AH_Horizontal
L1: 12u; IND_4532-WE-PD2_WRE-L
L2: 10u; L_Bourns_SRN6045TA
Rcomp1: 8.87k; R_0402_1005Metric_Pad0.72x0.64mm_HandSolder
Renb1: 100k; R_0402_1005Metric_Pad0.72x0.64mm_HandSolder
Rent1: 261k; R_0402_1005Metric_Pad0.72x0.64mm_HandSolder
Rfbb1: 22.1k; R_0402_1005Metric_Pad0.72x0.64mm_HandSolder
Rfbb2: 6.04k; R_0402_1005Metric_Pad0.72x0.64mm_HandSolder
Rfbt1: 100k; R_0402_1005Metric_Pad0.72x0.64mm_HandSolder
Rfbt2: 102k; R_0402_1005Metric_Pad0.72x0.64mm_HandSolder
Rmode1: 24.9k; R_0402_1005Metric_Pad0.72x0.64mm_HandSolder
U31: XTPS55285VALR; TPS55285
U32: TPS54202DDC; SOT-23-6
U33: LM2776; SOT-23-6

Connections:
/Power Supply/3.3V: Cff1.2, Cout1.2, L1.2, Rfbt1.1; also elsewhere on the board
/Power Supply/5V: C18.2, Cout3.1, Coutx1.1, Coutx3.1, Rfbt2.1, U31.9 (VOUT), U33.3 (VIN); also elsewhere on the board
/Power Supply/-5V: C19.2, U33.1 (VOUT); also elsewhere on the board
/Power Supply/WallAdpt: Cin1.1, Cin3.2, Cinx1.1, Cinx2.1, J9.1, Rent1.1, U31.5 (VIN), U32.3 (VIN)
GND: C18.1, C19.1, Ccomp1.2, Ccomp2.2, Cin1.2, Cin3.1, Cinx1.2, Cinx2.2, Cout1.1, Cout3.2, Coutx1.2, Coutx3.2, Cvcc1.2, J9.2, Renb1.2, Rfbb1.2, Rfbb2.2, Rmode1.2, U31.7 (PGND), U31.12 (AGND), U32.1 (GND), U33.2 (GND); also elsewhere on the board
unnamed: Ccomp2.1, Rcomp1.2
unnamed: Cboot2.2, U31.15 (BOOT1)
unnamed: Cboot3.2, U31.14 (BOOT2)
unnamed: Ccomp1.1, Rcomp1.1, U31.11 (COMP)
unnamed: Renb1.1, Rent1.2, U31.4 (EN_UVLO)
unnamed: Rfbb2.1, Rfbt2.2, U31.10 (FB_INT_N)
unnamed: Rmode1.1, U31.1 (MODE)
unnamed: Cboot2.1, L2.2, U31.6 (SW1)
unnamed: Cboot3.1, L2.1, U31.8 (SW2)
unnamed: Cvcc1.1, U31.13 (VCC)
unnamed: Cboot1.1, U32.6 (BOOT)
unnamed: Cff1.1, Rfbb1.1, Rfbt1.2, U32.4 (FB)
unnamed: Cboot1.2, L1.1, U32.2 (SW)
unnamed: C17.2, U33.5 (C1+)
unnamed: C17.1, U33.6 (C1-)

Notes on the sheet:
Switching Buck Converter
Inverting Switched Capacitor Regulator
Switching Buck-Boost Converter

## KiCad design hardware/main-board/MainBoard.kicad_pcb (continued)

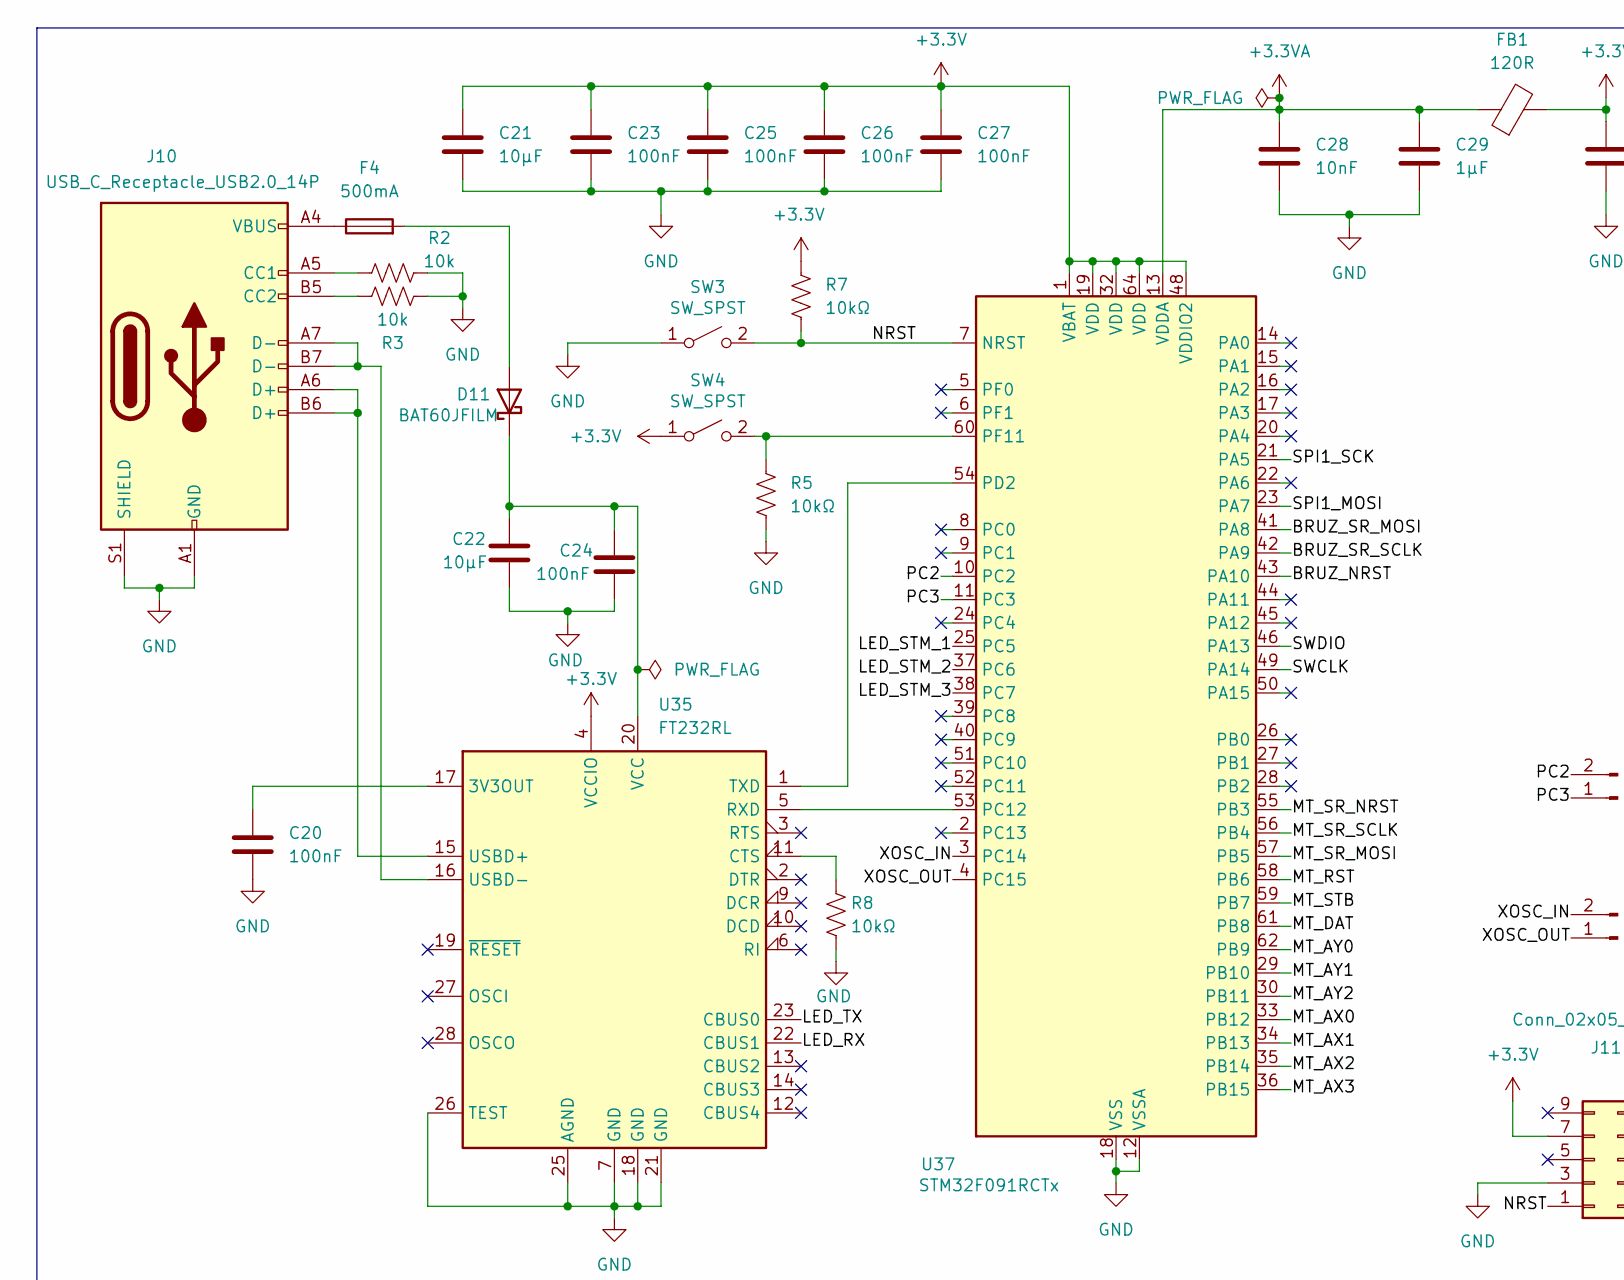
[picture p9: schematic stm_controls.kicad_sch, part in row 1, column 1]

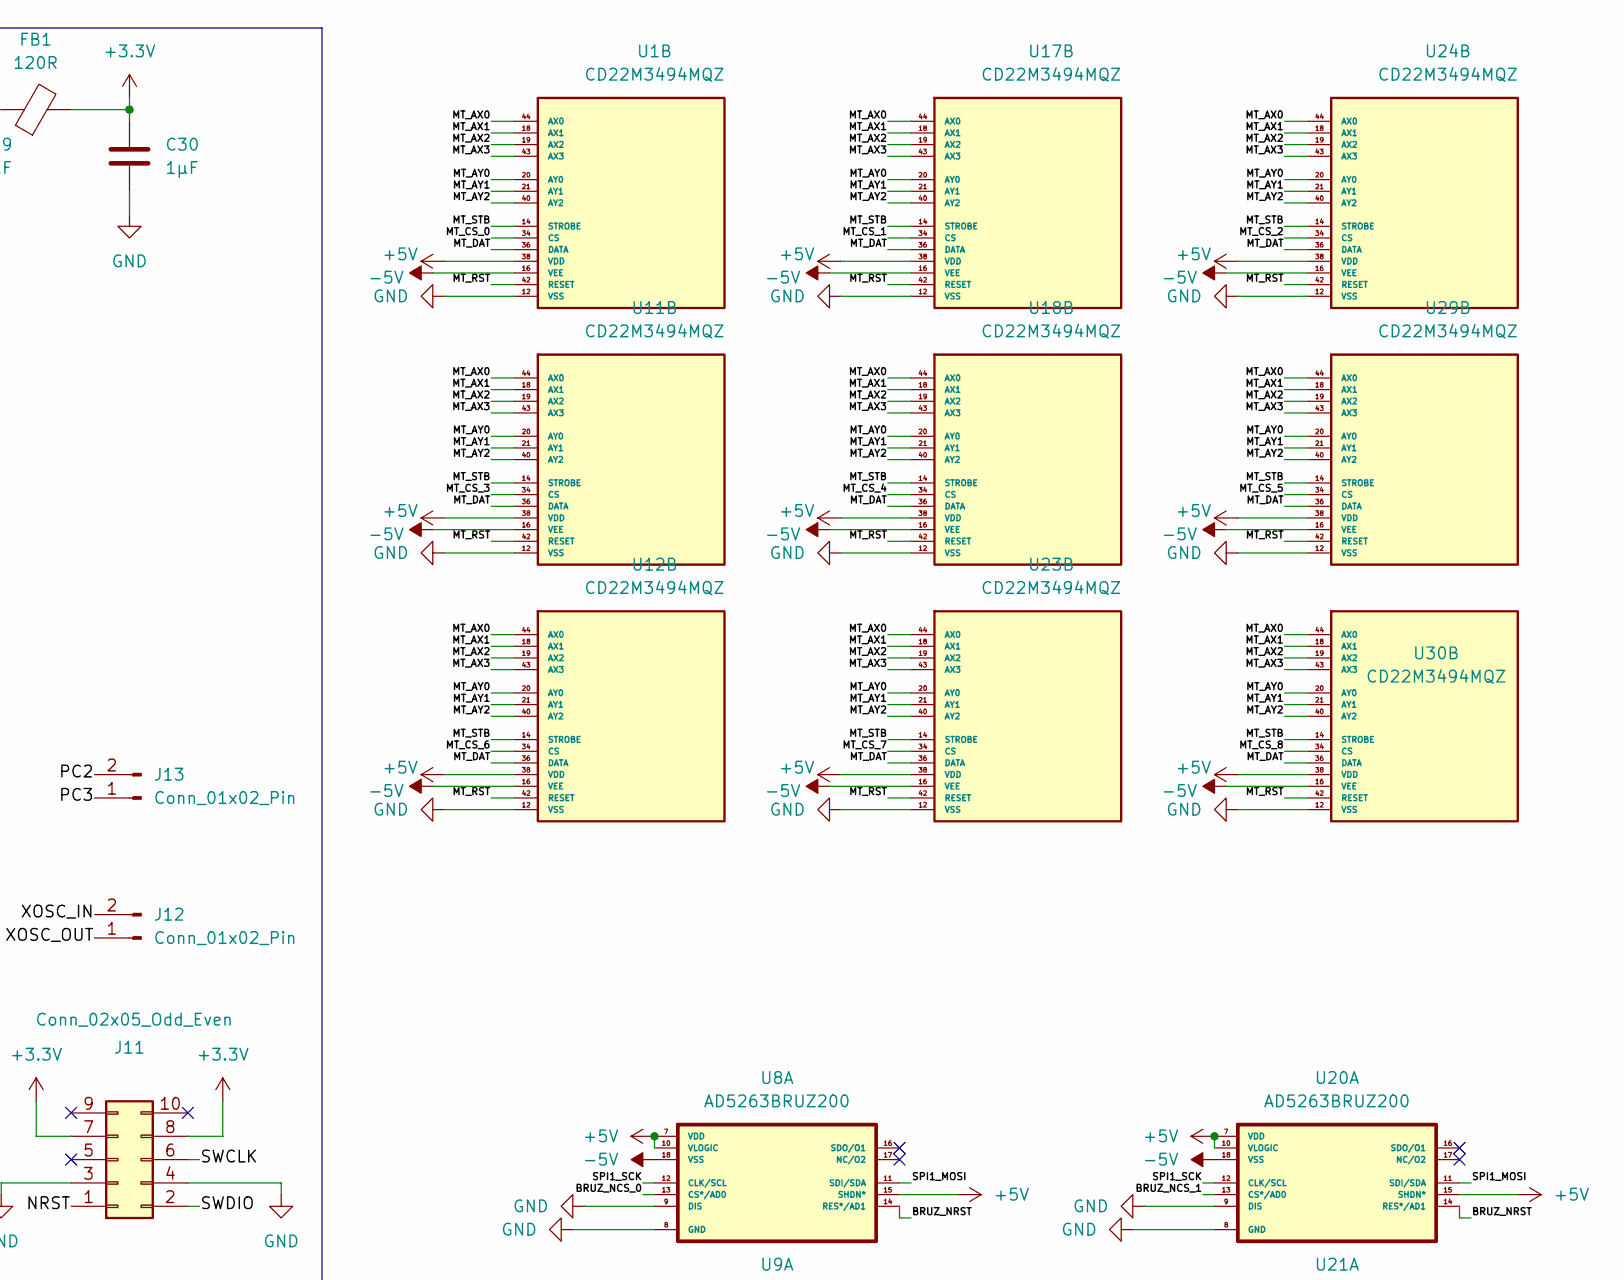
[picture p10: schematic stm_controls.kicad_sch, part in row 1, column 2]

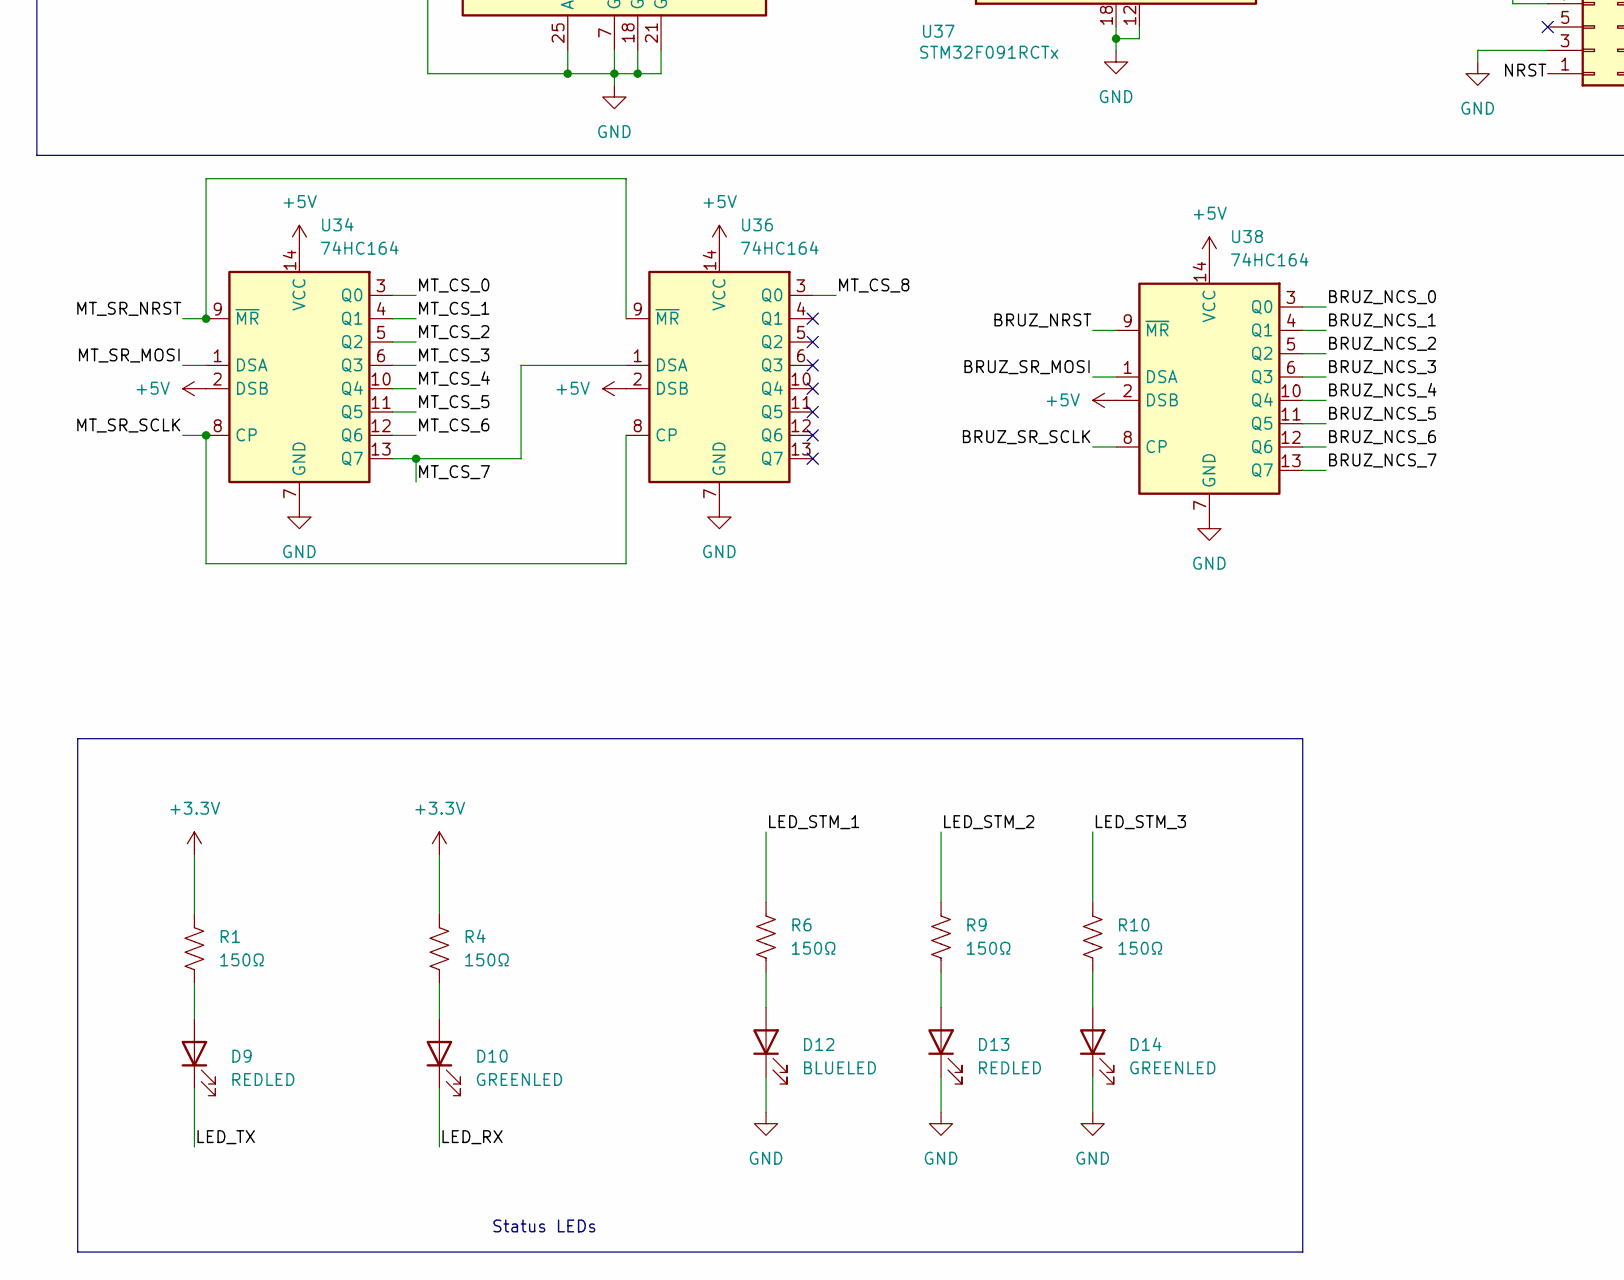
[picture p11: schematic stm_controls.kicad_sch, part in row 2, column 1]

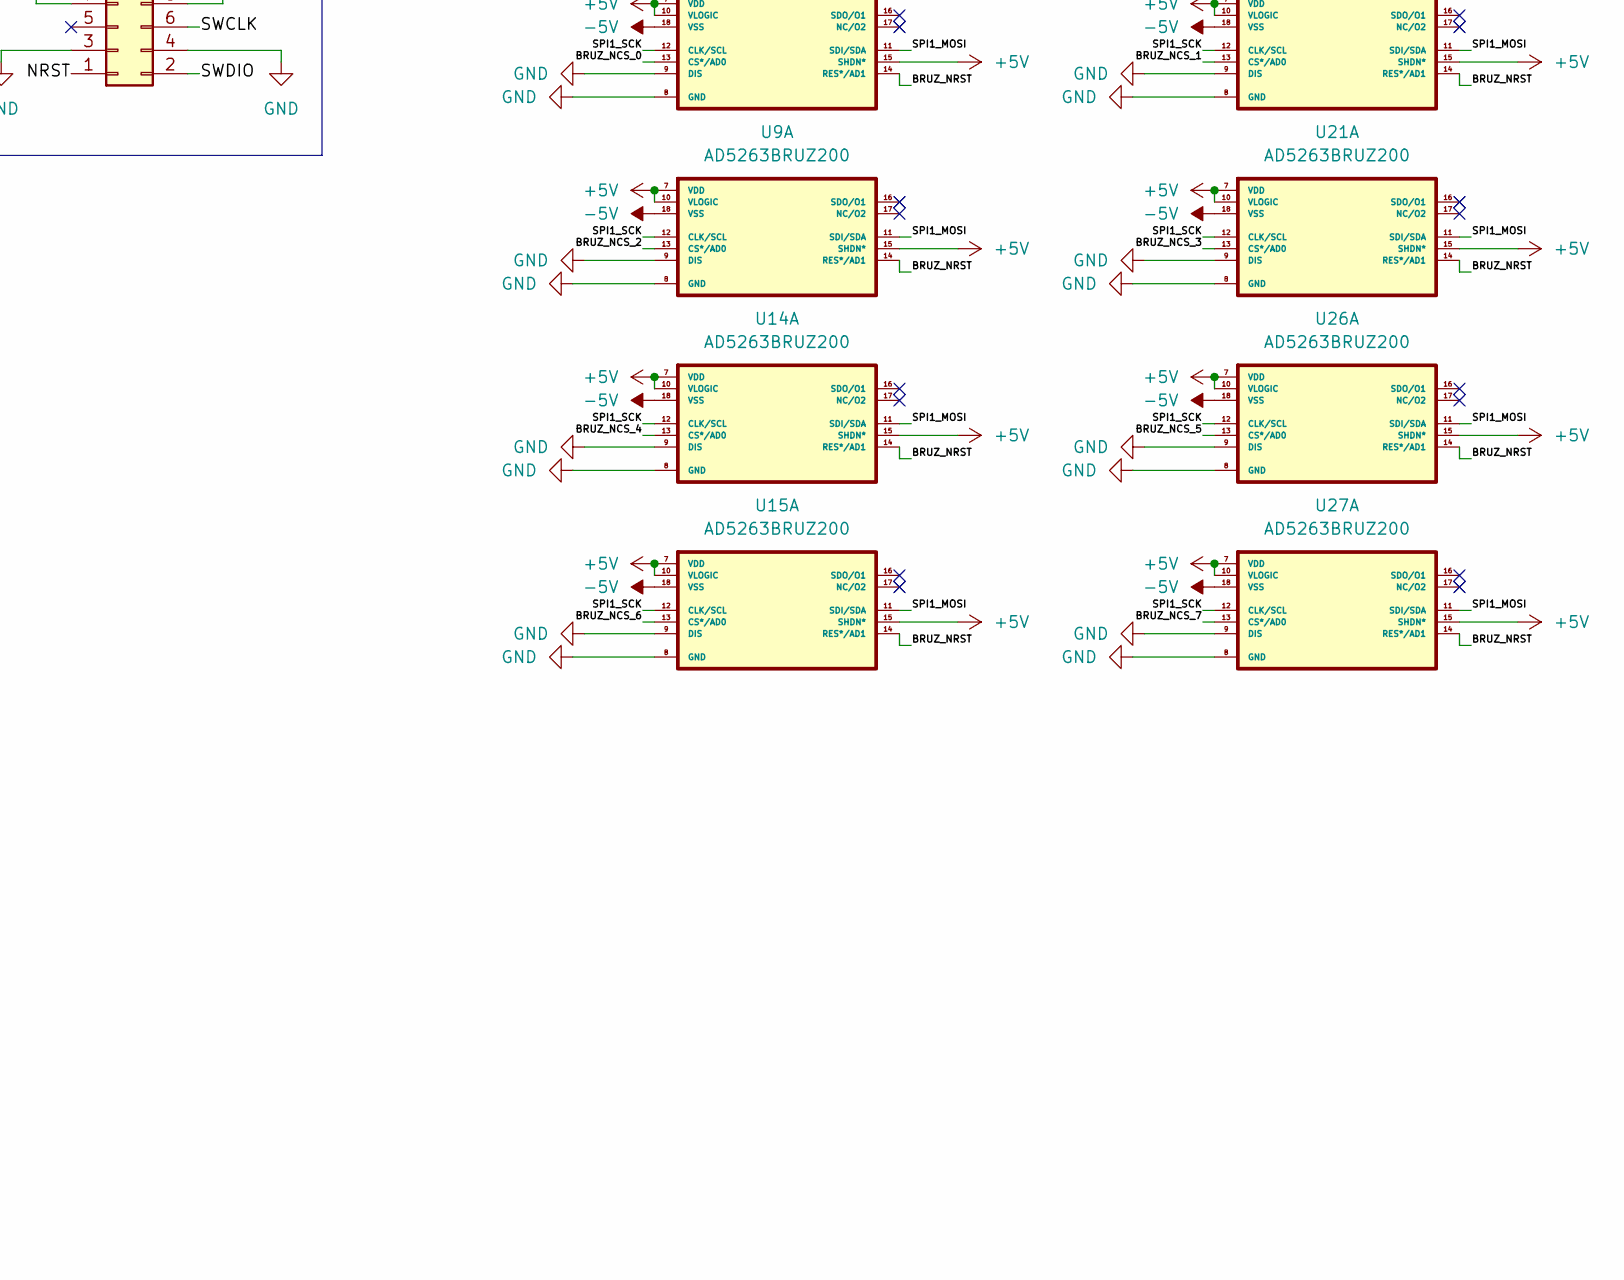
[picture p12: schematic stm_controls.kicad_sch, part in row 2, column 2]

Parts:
C20, C23, C24, C25, C26, C27: 100nF; C_0603_1608Metric_Pad1.08x0.95mm_HandSolder
C21, C22: 10µF; C_0603_1608Metric_Pad1.08x0.95mm_HandSolder
C28: 10nF; C_0603_1608Metric_Pad1.08x0.95mm_HandSolder
C29, C30: 1µF; C_0603_1608Metric_Pad1.08x0.95mm_HandSolder
D9, D13: REDLED; D_0805_2012Metric_Pad1.15x1.40mm_HandSolder
D10, D14: GREENLED; D_0805_2012Metric_Pad1.15x1.40mm_HandSolder
D11: BAT60JFILM; D_SOD-323_HandSoldering
D12: BLUELED; D_0805_2012Metric_Pad1.15x1.40mm_HandSolder
F4: 500mA; Fuse_0603_1608Metric_Pad1.05x0.95mm_HandSolder
FB1: 120R; L_0603_1608Metric_Pad1.05x0.95mm_HandSolder
J10: USB_C_Receptacle_USB2.0_14P; USB_C_Receptacle_G-Switch_GT-USB-7010ASV
J11: Conn_02x05_Odd_Even; PinHeader_2x05_P2.54mm_Vertical
J12, J13: Conn_01x02_Pin; PinSocket_1x02_P2.54mm_Vertical
R1, R4, R6, R9, R10: 150Ω; R_0603_1608Metric_Pad0.98x0.95mm_HandSolder
R2, R3: 10k; R_0603_1608Metric_Pad0.98x0.95mm_HandSolder
R5, R7, R8: 10kΩ; R_0603_1608Metric_Pad0.98x0.95mm_HandSolder
SW3, SW4: SW_SPST; SW_SPST_SKQG_WithoutStem
U1, U11, U12, U17, U18, U23, U24, U29, U30: CD22M3494MQZ; PLCC44_16P66X16P66_INR-M; PARTREV September 2011
U8, U9, U14, U15, U20, U21, U26, U27: AD5263BRUZ200; SOP65P640X120-24N
U34, U36, U38: 74HC164; SOIC-14_3.9x8.7mm_P1.27mm
U35: FT232RL; SSOP-28_5.3x10.2mm_P0.65mm
U37: STM32F091RCTx; LQFP-64_10x10mm_P0.5mm

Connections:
+3.3V: C21.1, C23.1, C25.1, C26.1, C27.1, C30.1, FB1.2, J11.7, J11.8, R1.1, R4.1, R7.1, SW4.1 (A), U35.4 (VCCIO), U37.1 (VBAT), U37.19 (VDD), U37.32 (VDD), U37.48 (VDDIO2), U37.64 (VDD); also elsewhere on the board
+3.3VA: C28.1, C29.1, FB1.1, U37.13 (VDDA)
+5V: U1.38 (VDD), U8.7 (VDD), U8.10 (VLOGIC), U8.15 (SHDN*), U9.7 (VDD), U9.10 (VLOGIC), U9.15 (SHDN*), U11.38 (VDD), U12.38 (VDD), U14.7 (VDD), U14.10 (VLOGIC), U14.15 (SHDN*), U15.7 (VDD), U15.10 (VLOGIC), U15.15 (SHDN*), U17.38 (VDD), U18.38 (VDD), U20.7 (VDD), U20.10 (VLOGIC), U20.15 (SHDN*), U21.7 (VDD), U21.10 (VLOGIC), U21.15 (SHDN*), U23.38 (VDD), U24.38 (VDD), U26.7 (VDD), U26.10 (VLOGIC), U26.15 (SHDN*), U27.7 (VDD), U27.10 (VLOGIC), U27.15 (SHDN*), U29.38 (VDD), U30.38 (VDD), U34.2 (DSB), U34.14 (VCC), U36.2 (DSB), U36.14 (VCC), U38.2 (DSB), U38.14 (VCC); also elsewhere on the board
-5V: U1.16 (VEE), U8.18 (VSS), U9.18 (VSS), U11.16 (VEE), U12.16 (VEE), U14.18 (VSS), U15.18 (VSS), U17.16 (VEE), U18.16 (VEE), U20.18 (VSS), U21.18 (VSS), U23.16 (VEE), U24.16 (VEE), U26.18 (VSS), U27.18 (VSS), U29.16 (VEE), U30.16 (VEE); also elsewhere on the board
/Cell_1_Buff: U1.13 (Y6); also elsewhere on the board
/Cell_1_Out: U18.10 (Y7); also elsewhere on the board
/Cell_2_Buff: U1.10 (Y7); also elsewhere on the board
/MicroController/BRUZ_NCS_0: U8.13 (CS*/AD0), U38.3 (Q0)
/MicroController/BRUZ_NCS_1: U20.13 (CS*/AD0), U38.4 (Q1)
/MicroController/BRUZ_NCS_2: U9.13 (CS*/AD0), U38.5 (Q2)
/MicroController/BRUZ_NCS_3: U21.13 (CS*/AD0), U38.6 (Q3)
/MicroController/BRUZ_NCS_4: U14.13 (CS*/AD0), U38.10 (Q4)
/MicroController/BRUZ_NCS_5: U26.13 (CS*/AD0), U38.11 (Q5)
/MicroController/BRUZ_NCS_6: U15.13 (CS*/AD0), U38.12 (Q6)
/MicroController/BRUZ_NCS_7: U27.13 (CS*/AD0), U38.13 (Q7)
/MicroController/BRUZ_NRST: U8.14 (RES*/AD1), U9.14 (RES*/AD1), U14.14 (RES*/AD1), U15.14 (RES*/AD1), U20.14 (RES*/AD1), U21.14 (RES*/AD1), U26.14 (RES*/AD1), U27.14 (RES*/AD1), U37.43 (PA10), U38.9 (~MR)
/MicroController/BRUZ_SR_MOSI: U37.41 (PA8), U38.1 (DSA)
/MicroController/BRUZ_SR_SCLK: U37.42 (PA9), U38.8 (CP)
/MicroController/LED_RX: D10.1 (K), U35.22 (CBUS1)
/MicroController/LED_STM_1: R6.1, U37.25 (PC5)
/MicroController/LED_STM_2: R9.1, U37.37 (PC6)
/MicroController/LED_STM_3: R10.1, U37.38 (PC7)
/MicroController/LED_TX: D9.1 (K), U35.23 (CBUS0)
/MicroController/MT_AX0: U1.44 (AX0), U11.44 (AX0), U12.44 (AX0), U17.44 (AX0), U18.44 (AX0), U23.44 (AX0), U24.44 (AX0), U29.44 (AX0), U30.44 (AX0), U37.33 (PB12)
/MicroController/MT_AX1: U1.18 (AX1), U11.18 (AX1), U12.18 (AX1), U17.18 (AX1), U18.18 (AX1), U23.18 (AX1), U24.18 (AX1), U29.18 (AX1), U30.18 (AX1), U37.34 (PB13)
/MicroController/MT_AX2: U1.19 (AX2), U11.19 (AX2), U12.19 (AX2), U17.19 (AX2), U18.19 (AX2), U23.19 (AX2), U24.19 (AX2), U29.19 (AX2), U30.19 (AX2), U37.35 (PB14)
/MicroController/MT_AX3: U1.43 (AX3), U11.43 (AX3), U12.43 (AX3), U17.43 (AX3), U18.43 (AX3), U23.43 (AX3), U24.43 (AX3), U29.43 (AX3), U30.43 (AX3), U37.36 (PB15)
/MicroController/MT_AY0: U1.20 (AY0), U11.20 (AY0), U12.20 (AY0), U17.20 (AY0), U18.20 (AY0), U23.20 (AY0), U24.20 (AY0), U29.20 (AY0), U30.20 (AY0), U37.62 (PB9)
/MicroController/MT_AY1: U1.21 (AY1), U11.21 (AY1), U12.21 (AY1), U17.21 (AY1), U18.21 (AY1), U23.21 (AY1), U24.21 (AY1), U29.21 (AY1), U30.21 (AY1), U37.29 (PB10)
/MicroController/MT_AY2: U1.40 (AY2), U11.40 (AY2), U12.40 (AY2), U17.40 (AY2), U18.40 (AY2), U23.40 (AY2), U24.40 (AY2), U29.40 (AY2), U30.40 (AY2), U37.30 (PB11)
/MicroController/MT_CS_0: U1.34 (CS), U34.3 (Q0)
/MicroController/MT_CS_1: U17.34 (CS), U34.4 (Q1)
/MicroController/MT_CS_2: U24.34 (CS), U34.5 (Q2)
/MicroController/MT_CS_3: U11.34 (CS), U34.6 (Q3)
/MicroController/MT_CS_4: U18.34 (CS), U34.10 (Q4)
/MicroController/MT_CS_5: U29.34 (CS), U34.11 (Q5)
/MicroController/MT_CS_6: U12.34 (CS), U34.12 (Q6)
/MicroController/MT_CS_7: U23.34 (CS), U34.13 (Q7), U36.1 (DSA)
/MicroController/MT_CS_8: U30.34 (CS), U36.3 (Q0)
/MicroController/MT_DAT: U1.36 (DATA), U11.36 (DATA), U12.36 (DATA), U17.36 (DATA), U18.36 (DATA), U23.36 (DATA), U24.36 (DATA), U29.36 (DATA), U30.36 (DATA), U37.61 (PB8)
/MicroController/MT_RST: U1.42 (RESET), U11.42 (RESET), U12.42 (RESET), U17.42 (RESET), U18.42 (RESET), U23.42 (RESET), U24.42 (RESET), U29.42 (RESET), U30.42 (RESET), U37.58 (PB6)
/MicroController/MT_SR_MOSI: U34.1 (DSA), U37.57 (PB5)
/MicroController/MT_SR_NRST: U34.9 (~MR), U36.9 (~MR), U37.55 (PB3)
/MicroController/MT_SR_SCLK: U34.8 (CP), U36.8 (CP), U37.56 (PB4)
/MicroController/MT_STB: U1.14 (STROBE), U11.14 (STROBE), U12.14 (STROBE), U17.14 (STROBE), U18.14 (STROBE), U23.14 (STROBE), U24.14 (STROBE), U29.14 (STROBE), U30.14 (STROBE), U37.59 (PB7)
/MicroController/NRST: J11.1, R7.2, SW3.2 (B), U37.7 (NRST)
/MicroController/PC2: J13.2, U37.10 (PC2)
/MicroController/PC3: J13.1, U37.11 (PC3)
/MicroController/SPI1_MOSI: U8.11 (SDI/SDA), U9.11 (SDI/SDA), U14.11 (SDI/SDA), U15.11 (SDI/SDA), U20.11 (SDI/SDA), U21.11 (SDI/SDA), U26.11 (SDI/SDA), U27.11 (SDI/SDA), U37.23 (PA7)
/MicroController/SPI1_SCK: U8.12 (CLK/SCL), U9.12 (CLK/SCL), U14.12 (CLK/SCL), U15.12 (CLK/SCL), U20.12 (CLK/SCL), U21.12 (CLK/SCL), U26.12 (CLK/SCL), U27.12 (CLK/SCL), U37.21 (PA5)
/MicroController/SWCLK: J11.6, U37.49 (PA14)
/MicroController/SWDIO: J11.2, U37.46 (PA13)
/MicroController/XOSC_IN: J12.2, U37.3 (PC14)
/MicroController/XOSC_OUT: J12.1, U37.4 (PC15)
/STD1/C3_in: U17.8 (X10); also elsewhere on the board
/STD1/C3_out: U17.9 (X11); also elsewhere on the board
/STD1/C4_out: U17.7 (X9); also elsewhere on the board
/STD1/R2_out: U18.7 (X9); also elsewhere on the board
/STD1/R4_in: U18.8 (X10); also elsewhere on the board
/STD1/R4_out: U18.9 (X11); also elsewhere on the board
/STD1/Y5: U17.15 (Y5); also elsewhere on the board
/STD1/Y6: U17.13 (Y6); also elsewhere on the board
/STD1/Y7: U17.10 (Y7); also elsewhere on the board
/STD1_Y0: U18.17 (Y4); also elsewhere on the board
/STD1_Y1: U18.15 (Y5); also elsewhere on the board
/STD1_Y2: U18.13 (Y6); also elsewhere on the board
/STD2_Y0: U1.2 (X14); also elsewhere on the board
/STD2_Y1: U1.3 (X15); also elsewhere on the board
/STD2_Y2: U1.4 (X6); also elsewhere on the board
/STD3/Y0: U1.5 (X7); also elsewhere on the board
/STD3/Y1: U1.6 (X8); also elsewhere on the board
/STD3/Y2: U1.7 (X9); also elsewhere on the board
/STD_Out: U1.8 (X10); also elsewhere on the board
GND: C20.2, C21.2, C22.2, C23.2, C24.2, C25.2, C26.2, C27.2, C28.2, C29.2, C30.2, D12.1 (K), D13.1 (K), D14.1 (K), J10.A1 (GND), J10.A12 (GND), J10.B1 (GND), J10.B12 (GND), J10.S1 (SHIELD), J11.3, J11.4, R2.2, R3.2, R5.2, R8.2, SW3.1 (A), U1.12 (VSS), U8.8 (GND), U8.9 (DIS), U9.8 (GND), U9.9 (DIS), U11.12 (VSS), U12.12 (VSS), U14.8 (GND), U14.9 (DIS), U15.8 (GND), U15.9 (DIS), U17.12 (VSS), U17.17 (Y4), U18.12 (VSS), U20.8 (GND), U20.9 (DIS), U21.8 (GND), U21.9 (DIS), U23.12 (VSS), U24.12 (VSS), U26.8 (GND), U26.9 (DIS), U27.8 (GND), U27.9 (DIS), U29.12 (VSS), U30.12 (VSS), U34.7 (GND), U35.7 (GND), U35.18 (GND), U35.21 (GND), U35.25 (AGND), U35.26 (TEST), U36.7 (GND), U37.12 (VSSA), U37.18 (VSS), U37.31 (VSS), U37.47 (VSS), U37.63 (VSS), U38.7 (GND); also elsewhere on the board
unnamed: D9.2 (A), R1.2
unnamed: D10.2 (A), R4.2
unnamed: D11.2 (A), F4.2
unnamed: C22.1, C24.1, D11.1 (K), U35.20 (VCC)
unnamed: D12.2 (A), R6.2
unnamed: D13.2 (A), R9.2
unnamed: D14.2 (A), R10.2
unnamed: F4.1, J10.A4 (VBUS), J10.A9 (VBUS), J10.B4 (VBUS), J10.B9 (VBUS)
unnamed: J10.A5 (CC1), R2.1
unnamed: J10.B5 (CC2), R3.1
unnamed: R5.1, SW4.2 (B), U37.60 (PF11)
unnamed: C20.1, U35.17 (3V3OUT)
unnamed: R8.1, U35.11 (CTS)
unnamed: U35.5 (RXD), U37.53 (PC12)
unnamed: U35.1 (TXD), U37.54 (PD2)
unnamed: J10.A6 (D+), J10.B6 (D+), U35.15 (USBD+)
unnamed: J10.A7 (D-), J10.B7 (D-), U35.16 (USBD-)

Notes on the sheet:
Status LEDs



Board: 4 copper layers, 120.0 x 135.0 mm, 140 parts (16 on the bottom side), 257 nets.

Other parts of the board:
Brick: LOGO

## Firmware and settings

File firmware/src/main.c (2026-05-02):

// my libs
#include "main.h"
#include "init.h"
#include "bruz200.h"
#include "cd22m.h"
#include "shift_registers.h"
#include "single_cell.h"

// c libs
#include <stdint.h>
#include <stdbool.h>
#include <string.h>

#define REAL_BOARD
#define REAL_CONFIG
// #define MEM_DUMP

#define WAIT_FOR_UART_TX while (!(USART5->ISR & USART_ISR_TXE))
#ifdef REAL_BOARD
  #define NUM_OF_CROSSBARS      9
  #define NUM_OF_POTS           24
#endif
#ifdef SINGLE_CELL
  #define NUM_OF_CROSSBARDS     2
  #define NUM_OF_POTS           6
#endif
#define NUM_OF_CROSSBAR_CONS  128
#define MAX_POT_RES           128
#define ERROR_DELAY           2000

uint8_t crossbar_order[9] = {
  0, 3, 6,
  1, 4, 7,
  2, 5, 8
};

int main(void)
{
  SPI_HandleTypeDef hspi;
  HAL_GPIO_WritePin(GPIOC, GPIO_PIN_6, 1);

  HAL_Init();
  internal_clock();
  setup_uart();
  setup_spi(&hspi);
  setup_gpios();

  // var inits for loop
  board_state_t state = IDLE;
  uint8_t crossbar_cons[NUM_OF_CROSSBARS][NUM_OF_CROSSBAR_CONS] = {0};
  uint8_t pot_resistances[NUM_OF_POTS] = {0};
  uint8_t rx;

  uint8_t cur_cb;
  uint8_t cur_pot;

  reset_crossbars();
  reset_pots();

  while (true) {  

    if (state == ERROR_STATE) {
      HAL_GPIO_WritePin(GPIOC, GPIO_PIN_6, 1);
    }

    if (state == IDLE) {
      HAL_GPIO_WritePin(GPIOC, GPIO_PIN_7, 1);
    }

    if ((USART5->ISR & USART_ISR_RXNE)) {
      HAL_GPIO_WritePin(GPIOC, GPIO_PIN_6, 0);
      HAL_GPIO_WritePin(GPIOC, GPIO_PIN_7, 0);
      rx = USART5->RDR;

      if (rx == RESET_CONFIG) {
        state = IDLE;

        memset(crossbar_cons,   0, sizeof(crossbar_cons));
        memset(pot_resistances, 1, sizeof(pot_resistances));

        reset_crossbars();
        reset_pots();
        sr_reset(BRUZ_SR);
        sr_reset(CD22M_SR);

        WAIT_FOR_UART_TX;
        USART5->TDR = RESET_SUCCESS;
        continue;
      }

      switch (state) {
        case IDLE:
          if (rx == START_CONFIG) { state = STARTING; }
          else                    { state = ERROR_STATE; }
          break;
        
        case ERROR_STATE:
          WAIT_FOR_UART_TX;
          USART5->TDR = UART_ERROR;
          break;
        
        case STARTING:
          if (rx == START_CONFIG) { 
            WAIT_FOR_UART_TX;
            USART5->TDR = READY_TO_START;
            state = UART_CONFIG;
          } else {
            state = ERROR_STATE;
          }
          break;

        case UART_CONFIG:
          if (get_prefix(rx) == START_CB) { 
            cur_cb = get_message(rx);
            state = CHOOSE_CB_CONNS;
          } else if (get_prefix(rx) == START_POT) {
            cur_pot = get_message(rx);
            state = CHOOSE_POT_RES;
          } else if (rx == END_CONFIG) {
            // HAL_GPIO_WritePin(GPIOC, GPIO_PIN_7, 1);

            reset_crossbars();
            reset_pots();

            sr_reset(BRUZ_SR);
            sr_reset(CD22M_SR);

            WAIT_FOR_UART_TX;
            USART5->TDR = CONFIG_SUCCESS;

            #ifdef MEM_DUMP
              for (int i = 0; i < NUM_OF_CROSSBARS; i++) {
                WAIT_FOR_UART_TX;
                USART5->TDR = i;
                for (int j = 0; j < NUM_OF_CROSSBAR_CONS; j++) {
                  if (crossbar_cons[i][j]) {
                    WAIT_FOR_UART_TX;
                    USART5->TDR = j;
                  }
                }
                WAIT_FOR_UART_TX;
                USART5->TDR = '\n';
              }

              for (int i = 0; i < NUM_OF_POTS; i++) {
                if (pot_resistances[i]) {
                  WAIT_FOR_UART_TX;
                  USART5->TDR = i;
                  WAIT_FOR_UART_TX;
                  USART5->TDR = pot_resistances[i];
                  WAIT_FOR_UART_TX;
                  USART5->TDR = '\n';
                }
              }
            #endif
            
            #ifdef REAL_CONFIG
            config_pots(pot_resistances, &hspi);

            sr_start(CD22M_SR);
            for (int i = 0; i < NUM_OF_CROSSBARS; i++) {
              for (int j = 0; j < NUM_OF_CROSSBAR_CONS; j++) {
                if (crossbar_cons[crossbar_order[i]][j]) {
                  enable_connection(get_x(j), get_y(j));
                }
              }
              sr_shift_en(CD22M_SR);
            }
            state = IDLE;

            WAIT_FOR_UART_TX;
            #endif

          } else {
            state = ERROR_STATE;
          }
          break;

        case CHOOSE_CB_CONNS:
          if (rx < NUM_OF_CROSSBAR_CONS) {
            crossbar_cons[cur_cb][rx] = 1;
          }
          else if (rx == END_CB) { 
            state = UART_CONFIG;
            WAIT_FOR_UART_TX;
            USART5->TDR = RETURN_TO_CONFIG;
          }
          else { 
            state = ERROR; 
          }
          break;

        case CHOOSE_POT_RES: 
          if (rx < MAX_POT_RES) {
            pot_resistances[cur_pot] = rx;
            USART5->TDR = RETURN_TO_CONFIG;
            state = UART_CONFIG;
          } else { 
            state = ERROR_STATE;
          }
          break;
        default: break;
      }
    }
  }
}

void SysTick_Handler(void)
{
  HAL_IncTick();
}

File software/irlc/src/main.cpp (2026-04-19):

#include "core/compiler.hpp"
#include <array>
#include <boost/program_options.hpp>
#include <boost/program_options/options_description.hpp>
#include <boost/program_options/parsers.hpp>
#include <boost/program_options/value_semantic.hpp>
#include <cstddef>
#include <cstring>
#include <iostream>
#include <map>

using std::string;

namespace po = boost::program_options;

template <size_t N> consteval std::array<char, N> flagify(std::array<char, N> long_name) {
    std::array<char, N> out(long_name);
    std::replace(out.begin(), out.end(), '_', '-');
    return out;
}

template <std::size_t... Ns> auto consteval concatenate(const std::array<char, Ns> &...arrays) {
    std::array<char, ((Ns - 1) + ...) + 1> result;
    std::size_t index{};

    ((std::copy_n(arrays.begin(), Ns - 1, result.begin() + index), index += Ns - 1), ...);

    result[result.size() - 1] = '\0';

    return result;
}

IrlCompilerOptions build_compiler_options(std::map<std::string, po::variable_value> &vm);

int main(int argc, char *argv[]) {

    std::map<IrlCompilerOptionGroup, po::options_description> opt_groups{};
    for (auto opt : IRL_COMPILER_OPTION_GROUPS) {
        opt_groups.emplace(opt, po::options_description(ilrCompilerOptionGroupName(opt)));
    }

#define CHAR_ARR(word) std::to_array(word)

    // Actually the coolest pattern I've ever seen
#define FLAG_OPT(LONG_N, SHORT_N, MSG, CATEGORY)                                                   \
    do {                                                                                           \
        opt_groups[CATEGORY].add_options()(                                                        \
            concatenate(flagify(CHAR_ARR(QUOTE(LONG_N))), CHAR_ARR(","), CHAR_ARR(SHORT_N))        \
                .data(),                                                                           \
            MSG);                                                                                  \
    } while (0);
#define TYPED_OPT(LONG_N, SHORT_N, TYPE, DEFAULT, MSG, CATEGORY)                                   \
    do {                                                                                           \
        opt_groups[CATEGORY].add_options()(                                                        \
            concatenate(flagify(CHAR_ARR(QUOTE(LONG_N))), CHAR_ARR(","), CHAR_ARR(SHORT_N))        \
                .data(),                                                                           \
            po::value<TYPE>(), MSG);                                                               \
                                                                                                   \
    } while (0);

    // Like wtf even is this
    COMPILER_OPTIONS

#undef FLAG_OPT
#undef TYPED_OPT

    po::options_description cmdline_desc;

    for (auto &pair : opt_groups) {
        cmdline_desc.add(pair.second);
    }

    po::positional_options_description positional;
    positional.add(flagify(CHAR_ARR(EX_AND_QUOTE(INFILE_OPT))).data(), -1);

    po::variables_map vm;
    po::store(
        po::command_line_parser(argc, argv).options(cmdline_desc).positional(positional).run(), vm);
    po::store(po::parse_command_line(argc, argv, cmdline_desc), vm);
    po::notify(vm);

    IrlCompilerOptions opts = build_compiler_options(vm);

    IrlCompiler compiler(std::move(opts), std::cout);

    if (compiler.opts.help || argc == 1) {
        std::cout << "Usage:\n\n"
                  << "  irlc [OPTIONS] <input-file>\n";
        std::cout << cmdline_desc << std::endl;
        return -1;
    }

    return compiler.invoke();
}

IrlCompilerOptions build_compiler_options(std::map<std::string, po::variable_value> &vm) {

    // #define FLAG_OPT(LONG_N, SHORT_N, MSG, CATEGORY) \
    //     std::cout << QUOTE(LONG_N) << " - count: " << vm.count(flagify(QUOTE(LONG_N)).c_str()) <<
    //     "\n";
    // #define TYPED_OPT(LONG_N, SHORT_N, TYPE, MSG, CATEGORY) \
    //     std::cout << QUOTE(LONG_N) << " - count: " << vm.count(flagify(QUOTE(LONG_N)).c_str()) <<
    //     "\n"; COMPILER_OPTIONS
    // #undef FLAG_OPT
    // #undef TYPED_OPT

#define FLAG_OPT(LONG_N, SHORT_N, MSG, CATEGORY)                                                   \
    .LONG_N = vm.contains(flagify(CHAR_ARR(QUOTE(LONG_N))).data()),
#define TYPED_OPT(LONG_N, SHORT_N, TYPE, DEFAULT, MSG, CATEGORY)                                   \
    .LONG_N = vm.contains(flagify(CHAR_ARR(QUOTE(LONG_N))).data())                                 \
                  ? vm[flagify(CHAR_ARR(QUOTE(LONG_N))).data()].as<TYPE>()                         \
                  : DEFAULT,

    return {COMPILER_OPTIONS};

#undef FLAG_OPT
#undef TYPED_OPT
}

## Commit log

2026-01-23 version: Upgrade to KiCad 9
    [KiCad_Scheme.kicad_sch, untitled.kicad_sch]
2026-01-23 organization: Migrate to hardware dir
    [KiCad_Scheme.kicad_sch, MainBoard.kicad_sch, standard_cell.kicad_sch]
2026-01-28 feat: top level schem
    [MainBoard.kicad_sch]
2026-01-28 fix: top level sectioning
    [MainBoard.kicad_sch, standard_cell.kicad_sch]
2026-01-28 feat: added power amp to top
    [MainBoard.kicad_sch]
2026-02-06 Changed cell design added new resistors
    [standard_cell.kicad_sch]
2026-02-11 Power Supply schematic added and power amp design changed. Initial Design stage.
    [MainBoard.kicad_sch, PowerCircuit.kicad_sch]
2026-02-11 Clayton's fun routing fix
    [MainBoard.kicad_sch, standard_cell.kicad_sch]
2026-02-20 feat: Netlist graph for resistors and caps
2026-02-20 feat: base firmware drivers
2026-02-27 Added Digital Pot Symbol and created Senior Design Footprint Library
2026-03-04 added symbol and footprint for new crossbar MT8816
2026-03-04 symbol update
    [standard_cell.kicad_sch]
2026-03-04 feat: stm32 IC controls
    [stm_controls.kicad_sch]
2026-03-04 Big Changes in the Schematic World
    [MainBoard.kicad_sch, standard_cell.kicad_sch]
2026-03-06 God is Real, God is Real, Im not kidding this time I wouldn't joke about this
    [MainBoard.kicad_sch, stm_controls.kicad_sch]
2026-03-06 feat: reworked drivers
2026-03-06 Added TPS55285 Foot and Sym
    [PowerCircuit.kicad_sch]
2026-03-06 fortnite info cache
    [MainBoard.kicad_sch, PowerCircuit.kicad_sch, standard_cell.kicad_sch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]
2026-03-08 Updated Footprints and Controls
    [MainBoard.kicad_sch, PowerCircuit.kicad_sch, standard_cell.kicad_sch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]
2026-03-08 Designated majority of footprints
    [MainBoard.kicad_pcb, MainBoard.kicad_sch, PowerCircuit.kicad_sch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]
2026-03-09 Fully filled footprints
    [MainBoard.kicad_sch, standard_cell.kicad_sch, stm_controls.kicad_sch]
2026-03-10 PCB comps in, and formatted
    [MainBoard.kicad_pcb, MainBoard.kicad_sch, standard_cell.kicad_sch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]
2026-03-11 designed Power PCB section layout
    [MainBoard.kicad_pcb, MainBoard.kicad_sch, PowerCircuit.kicad_sch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]
2026-03-12 small edits with layout discussion
    [MainBoard.kicad_pcb]
2026-03-13 feat: drivers for demo
2026-03-13 Working on that PCP
    [MainBoard.kicad_pcb, standard_cell.kicad_sch, stm_controls.kicad_sch]
2026-03-13 The PCB is coming together
    [MainBoard.kicad_pcb, standard_cell.kicad_sch, stm_controls.kicad_sch]
2026-03-15 Added wiring to cells and compacted input
    [MainBoard.kicad_pcb, MainBoard.kicad_sch, stm_controls.kicad_sch]
2026-03-15 added some intercell connections
    [MainBoard.kicad_pcb]
2026-03-16 Squishing Standard Cells Together
    [MainBoard.kicad_pcb]
2026-03-16 started cross board traces for data and signal in bot cell
    [MainBoard.kicad_pcb]
2026-03-16 Standard cell 1 finalizations
    [MainBoard.kicad_pcb, MainBoard.kicad_sch]
2026-03-17 linked outside AX and AY and other controls
    [MainBoard.kicad_pcb]
2026-03-18 STD2 Analog
    [MainBoard.kicad_pcb]
2026-03-18 ran more control lines on cell 0 and 1
    [MainBoard.kicad_pcb]
2026-03-19 Standard cell 2
    [MainBoard.kicad_pcb, MainBoard.kicad_sch]
2026-03-19 feat: Board Info + wip on custom
2026-03-19 completed AX and AY on all cells, started ground and power plane
    [MainBoard.kicad_pcb]
2026-03-20 Almost done with the control
    [MainBoard.kicad_pcb]
2026-03-20 I Love You Big Sean
    [MainBoard.kicad_pcb]
2026-03-21 created power plane, tweeked track sizes
    [MainBoard.kicad_pcb]
2026-03-21 I think Parker would look good if he got shot in the head
    [MainBoard.kicad_pcb, MainBoard.kicad_sch]
2026-03-22 finalized input output and power plane
    [MainBoard.kicad_pcb]
2026-03-22 feat: Schematic changes for top level +/-5V
    [MainBoard.kicad_sch]
2026-03-22 feat: Routing for top level +/- 5V
    [MainBoard.kicad_pcb, MainBoard.kicad_sch]
2026-03-23 added ground conn and fixed switches
    [MainBoard.kicad_pcb, PowerCircuit.kicad_sch]
2026-03-23 feat: ERC + DRC fixes
    [MainBoard.kicad_pcb, MainBoard.kicad_sch, PowerCircuit.kicad_sch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]
2026-03-23 feat: Diodes bigger
    [MainBoard.kicad_pcb, standard_cell.kicad_sch]
2026-03-23 added drc rules for JLC
    [MainBoard.kicad_pcb]
2026-03-23 feat: Part nos plus some micro fixup
    [MainBoard.kicad_pcb, MainBoard.kicad_sch, PowerCircuit.kicad_sch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]
2026-03-24 finalized component list, fixed DRC errors
    [MainBoard.kicad_pcb, MainBoard.kicad_sch, PowerCircuit.kicad_sch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]
2026-03-24 Top 10 Minecraft Youtubers who have sworn
    [MainBoard.kicad_pcb]
2026-03-24 part numbers
    [MainBoard.kicad_pcb]
2026-03-25 feat: uart byte header
2026-03-27 Little Backup PCB Addition
    [SignleCellBoard.kicad_pcb, SignleCellBoard.kicad_sch, untitled.kicad_sch]
2026-03-27 fix: Cap allocaion values + opamp pin
2026-03-27 feat: Resistor quantization
2026-03-28 started single cell pcb
    [MainBoard.csv, SignleCellBoard.kicad_pcb]
2026-04-01 feat: WIP on board programmer
2026-04-03 feat: adding sr drivers
2026-04-03 feat: reset pots added
    [bruz200.c]
2026-04-08 feat: redo sr drivers
2026-04-08 fix: flagify uses std::array
    [main.cpp]
2026-04-08 fix: Chainedcrossbar vectors for msvc
2026-04-08 feat: Mock programming + flag fix
    [compiler.cpp, main.cpp]
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2026-04-13 feat: update for pcb testing
2026-04-13 fix: function definition clarity
    [shift_registers.c]
2026-04-19 feat: Begin crossbar fixer
    [crossbar-fixer.kicad_pcb, crossbar-fixer.kicad_sch]
2026-04-20 I ate the fillet 'o fish
    [crossbar-fixer.kicad_pcb, crossbar-fixer.kicad_sch]
2026-04-22 Parker Loves Furries
    [SignleCellBoard.kicad_pcb, SignleCellBoard.kicad_sch, untitled.kicad_sch]
2026-04-24 feat: Timing worst case
2026-04-24 I know of at least one
    [SignleCellBoard.kicad_pcb, SignleCellBoard.kicad_sch, untitled.kicad_sch]
2026-04-27 feat: WIP on manufacturability
    [SignleCellBoard.kicad_pcb]
2026-04-28 PCB done
    [SignleCellBoard-B_Cu.gbr, SignleCellBoard-B_Mask.gbr, SignleCellBoard-B_Silkscreen.gbr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]
2026-04-30 feat: simpler bruz drivers
2026-04-30 fix: bruz drivers
2026-04-30 feat: bruz latch enable fix
    [bruz200.c]
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2026-04-30 feat: programming real board
2026-04-30 feat: 0 resistance prevention
    [bruz200.c]
